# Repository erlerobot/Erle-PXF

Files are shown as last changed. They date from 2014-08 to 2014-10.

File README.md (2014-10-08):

Erle-PXF
===

Fork of the PXF board (http://github.com/diydrones/PXF) made by Erle Robotics.

This project is for developers, it will NOT be supported by the DIYDrones or Ardupilot suppoert forums for general users. This means we do not expect that this board will be plug and play, nor do we intend it to be.

Credit to Philip Rowse and Erle Robotics.

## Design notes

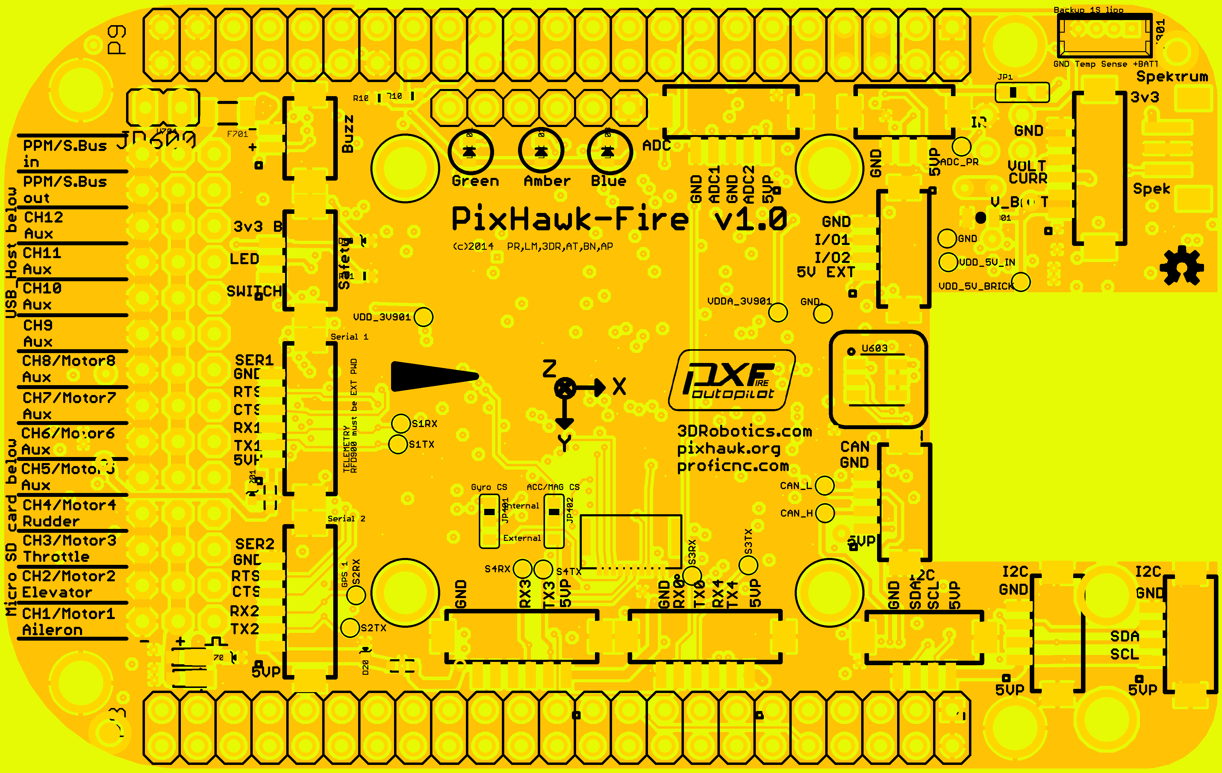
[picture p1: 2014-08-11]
3DModel/eagleUp/eagleUp_PixHawk_Fire_v1.1_board_top.png

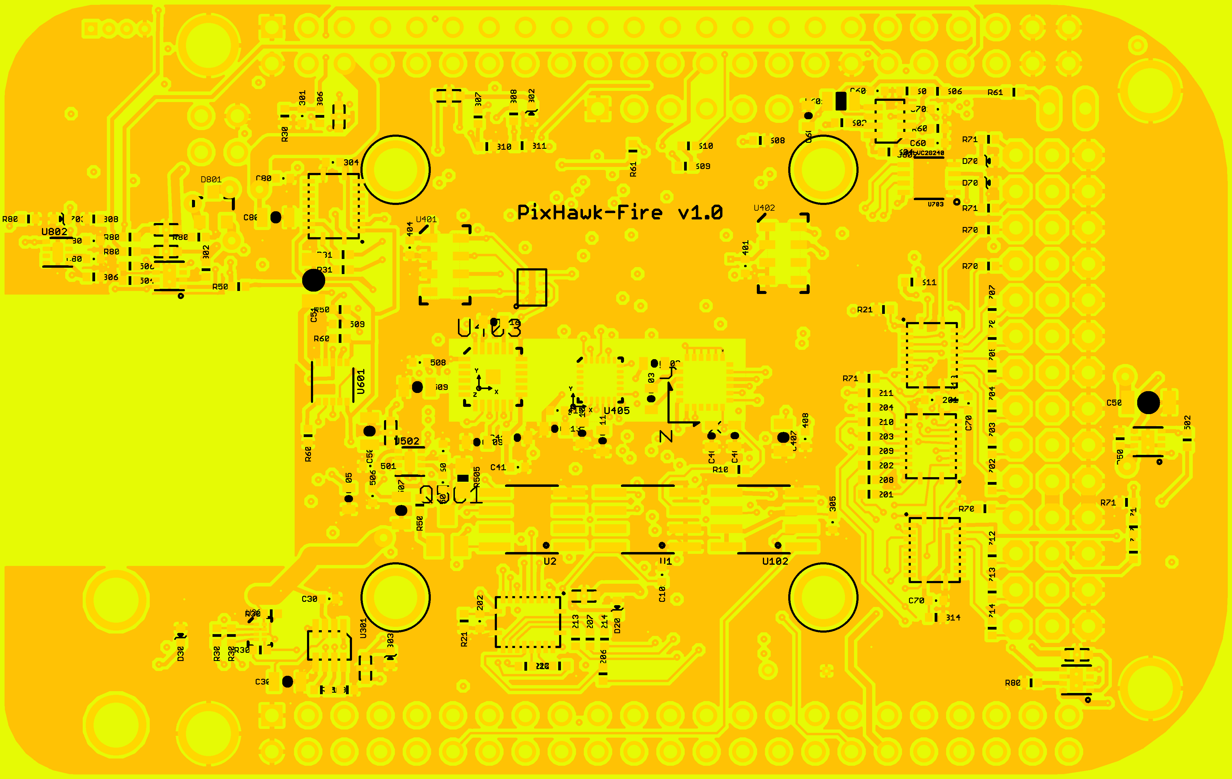
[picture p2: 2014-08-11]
3DModel/eagleUp/eagleUp_PixHawk_Fire_v1.1_board_bottom.png

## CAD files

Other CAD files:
3DModel/PXF-amarillo.skp

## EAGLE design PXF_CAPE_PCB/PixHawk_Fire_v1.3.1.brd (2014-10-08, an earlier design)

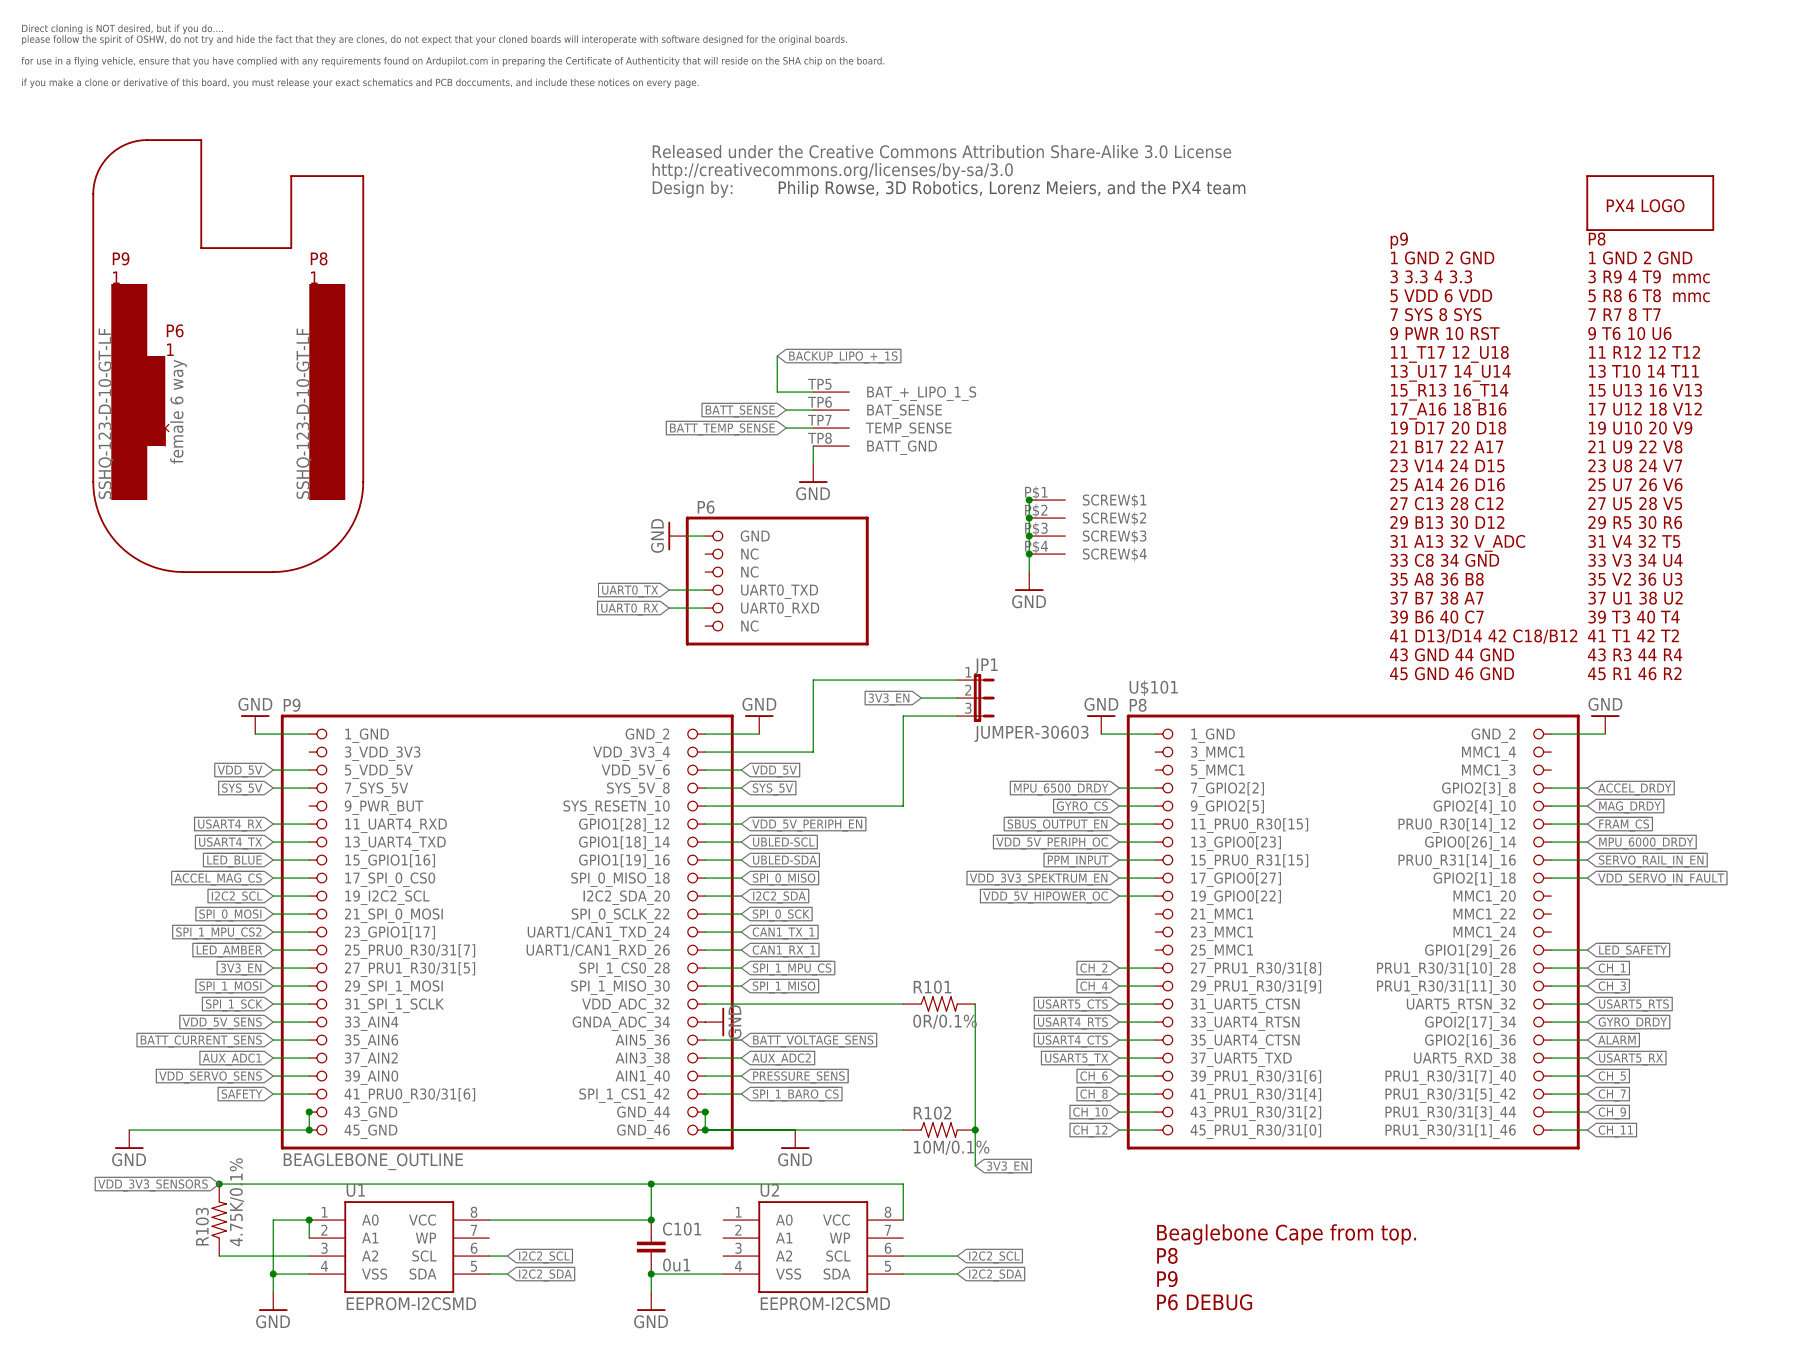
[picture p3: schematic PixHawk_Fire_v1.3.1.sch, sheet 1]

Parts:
C101: 0u1; 0402-CAP; PARTNO CC0402ZRY5V7BB104
JP1: JUMPER-30603; SJ_3_0603_PASTE1&2; PARTNO RC0603JR-070RL
R101: 0R/0.1%; 0402-RES; PARTNO RC0402FR-070RL
R102: 10M/0.1%; 0402-RES; PARTNO RC0402FR-0710ML
R103: 4.75K/0.1%; 0402-RES; PARTNO RC0402FR-074K75L
U1: EEPROM-I2CSMD; SO08; PARTNO AT24CS32-SSHM
U2: EEPROM-I2CSMD; SO08; PARTNO ATSHA204-SH-DA-TTR-ND
U$1: PX4-LOGO; PIXHAWK-FIRE-LOGO-30
U$6: CREATIVE_COMMONS
U$101: BEAGLEBONE_OUTLINE; BEAGLEBONE_SHIELD

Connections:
3V3_EN: JP1.2, R101.P$2 (2), R102.P$2 (2), U$101.73 (27_PRU1_R30/31[5]); also elsewhere on the board
3_VDD_3V3: U$101.49 (3_VDD_3V3)
!ACCEL_MAG_CS: U$101.63 (17_SPI_0_CS0); also elsewhere on the board
!FRAM_CS: U$101.12 (PRU0_R30[14]_12); also elsewhere on the board
!GYRO_CS: U$101.9 (9_GPIO2[5]); also elsewhere on the board
!LED_AMBER: U$101.71 (25_PRU0_R30/31[7]); also elsewhere on the board
!LED_BLUE: U$101.61 (15_GPIO1[16]); also elsewhere on the board
!LED_SAFETY: U$101.26 (GPIO1[29]_26); also elsewhere on the board
!SBUS_OUTPUT_EN: U$101.11 (11_PRU0_R30[15]); also elsewhere on the board
!VDD_5V_HIPOWER_OC: U$101.19 (19_GPIO0[22]); also elsewhere on the board
!VDD_5V_PERIPH_EN: U$101.58 (GPIO1[28]_12); also elsewhere on the board
!VDD_5V_PERIPH_OC: U$101.13 (13_GPIO0[23]); also elsewhere on the board
!VDD_SERVO_IN_FAULT: U$101.18 (GPIO2[1]_18); also elsewhere on the board
ACCEL_DRDY: U$101.8 (GPIO2[3]_8); also elsewhere on the board
ALARM: U$101.36 (GPIO2[16]_36); also elsewhere on the board
AUX_ADC1: U$101.83 (37_AIN2); also elsewhere on the board
AUX_ADC2: U$101.84 (AIN3_38); also elsewhere on the board
BACKUP_LIPO_+_1S: U$101.TP5 (BAT_+_LIPO_1_S); also elsewhere on the board
BATT_CURRENT_SENS: U$101.81 (35_AIN6); also elsewhere on the board
BATT_SENSE: U$101.TP6 (BAT_SENSE); also elsewhere on the board
BATT_TEMP_SENSE: U$101.TP7 (TEMP_SENSE); also elsewhere on the board
BATT_VOLTAGE_SENS: U$101.82 (AIN5_36); also elsewhere on the board
CH_1: U$101.28 (PRU1_R30/31[10]_28); also elsewhere on the board
CH_2: U$101.27 (27_PRU1_R30/31[8]); also elsewhere on the board
CH_3: U$101.30 (PRU1_R30/31[11]_30); also elsewhere on the board
CH_4: U$101.29 (29_PRU1_R30/31[9]); also elsewhere on the board
CH_5: U$101.40 (PRU1_R30/31[7]_40); also elsewhere on the board
CH_6: U$101.39 (39_PRU1_R30/31[6]); also elsewhere on the board
CH_7: U$101.42 (PRU1_R30/31[5]_42); also elsewhere on the board
CH_8: U$101.41 (41_PRU1_R30/31[4]); also elsewhere on the board
CH_9: U$101.44 (PRU1_R30/31[3]_44); also elsewhere on the board
CH_10: U$101.43 (43_PRU1_R30/31[2]); also elsewhere on the board
CH_11: U$101.46 (PRU1_R30/31[1]_46); also elsewhere on the board
CH_12: U$101.45 (45_PRU1_R30/31[0]); also elsewhere on the board
GND: C101.P$2 (2), R102.P$1 (1), U1.1 (A0), U1.2 (A1), U1.4 (VSS), U2.4 (VSS), U$101.1 (1_GND), U$101.2 (GND_2), U$101.47 (1_GND), U$101.48 (GND_2), U$101.80 (GNDA_ADC_34), U$101.89 (43_GND), U$101.90 (GND_44), U$101.91 (45_GND), U$101.92 (GND_46), U$101.93 (GND), U$101.P$1 (SCREW$1), U$101.P$2 (SCREW$2), U$101.P$3 (SCREW$3), U$101.P$4 (SCREW$4), U$101.TP8 (BATT_GND); also elsewhere on the board
GYRO_DRDY: U$101.34 (GPOI2[17]_34); also elsewhere on the board
I2C2_SCL: U1.6 (SCL), U2.6 (SCL), U$101.65 (19_I2C2_SCL); also elsewhere on the board
I2C2_SDA: U1.5 (SDA), U2.5 (SDA), U$101.66 (I2C2_SDA_20); also elsewhere on the board
MAG_DRDY: U$101.10 (GPIO2[4]_10); also elsewhere on the board
MPU_6000_DRDY: U$101.14 (GPIO0[26]_14); also elsewhere on the board
MPU_6500_DRDY: U$101.7 (7_GPIO2[2]); also elsewhere on the board
unnamed: R103.P$1 (1), U1.3 (A2)
unnamed: JP1.1, U$101.50 (VDD_3V3_4)
unnamed: JP1.3, U$101.56 (SYS_RESETN_10)
PPM_INPUT: U$101.15 (15_PRU0_R31[15]); also elsewhere on the board
PRESSURE_SENS: U$101.86 (AIN1_40); also elsewhere on the board
SAFETY: U$101.87 (41_PRU0_R30/31[6]); also elsewhere on the board
SERVO_RAIL_IN_!EN: U$101.16 (PRU0_R31[14]_16); also elsewhere on the board
SPI_0_MISO: U$101.64 (SPI_0_MISO_18); also elsewhere on the board
SPI_0_MOSI: U$101.67 (21_SPI_0_MOSI); also elsewhere on the board
SPI_0_SCK: U$101.68 (SPI_0_SCLK_22); also elsewhere on the board
SPI_1_!BARO_CS: U$101.88 (SPI_1_CS1_42); also elsewhere on the board
SPI_1_!MPU_CS: U$101.74 (SPI_1_CS0_28); also elsewhere on the board
SPI_1_!MPU_CS2: U$101.69 (23_GPIO1[17]); also elsewhere on the board
SPI_1_MISO: U$101.76 (SPI_1_MISO_30); also elsewhere on the board
SPI_1_MOSI: U$101.75 (29_SPI_1_MOSI); also elsewhere on the board
SPI_1_SCK: U$101.77 (31_SPI_1_SCLK); also elsewhere on the board
SYS_5V: U$101.53 (7_SYS_5V), U$101.54 (SYS_5V_8); also elsewhere on the board
UART0_RX: U$101.97 (UART0_RXD); also elsewhere on the board
UART0_TX: U$101.96 (UART0_TXD); also elsewhere on the board
UBLED-SCL: U$101.60 (GPIO1[18]_14); also elsewhere on the board
UBLED-SDA: U$101.62 (GPIO1[19]_16); also elsewhere on the board
USART4_CTS: U$101.35 (35_UART4_CTSN); also elsewhere on the board
USART4_RTS: U$101.33 (33_UART4_RTSN); also elsewhere on the board
USART4_RX: U$101.57 (11_UART4_RXD); also elsewhere on the board
USART4_TX: U$101.59 (13_UART4_TXD); also elsewhere on the board
USART5_CTS: U$101.31 (31_UART5_CTSN); also elsewhere on the board
USART5_RTS: U$101.32 (UART5_RTSN_32); also elsewhere on the board
USART5_RX: U$101.38 (UART5_RXD_38); also elsewhere on the board
USART5_TX: U$101.37 (37_UART5_TXD); also elsewhere on the board
VDD_3V3_SENSORS: C101.P$1 (1), R103.P$2 (2), U1.8 (VCC), U2.8 (VCC); also elsewhere on the board
VDD_3V3_SPEKTRUM_EN: U$101.17 (17_GPIO0[27]); also elsewhere on the board
VDD_5V: U$101.51 (5_VDD_5V), U$101.52 (VDD_5V_6); also elsewhere on the board
VDD_5V_SENS: U$101.79 (33_AIN4); also elsewhere on the board
VDD_ADC: R101.P$1 (1), U$101.78 (VDD_ADC_32)
VDD_SERVO_SENS: U$101.85 (39_AIN0); also elsewhere on the board

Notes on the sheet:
Beaglebone Cape from top. P8 P9 P6 DEBUG
Philip Rowse, 3D Robotics, Lorenz Meiers, and the PX4 team
Direct cloning is NOT desired, but if you do.... please follow the spirit of OSHW, do not try and hide the fact that they are clones, do not expect that your cloned boards will interoperate with software designed for the original boards. for use in a flying vehicle, ensure that you have complied wi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

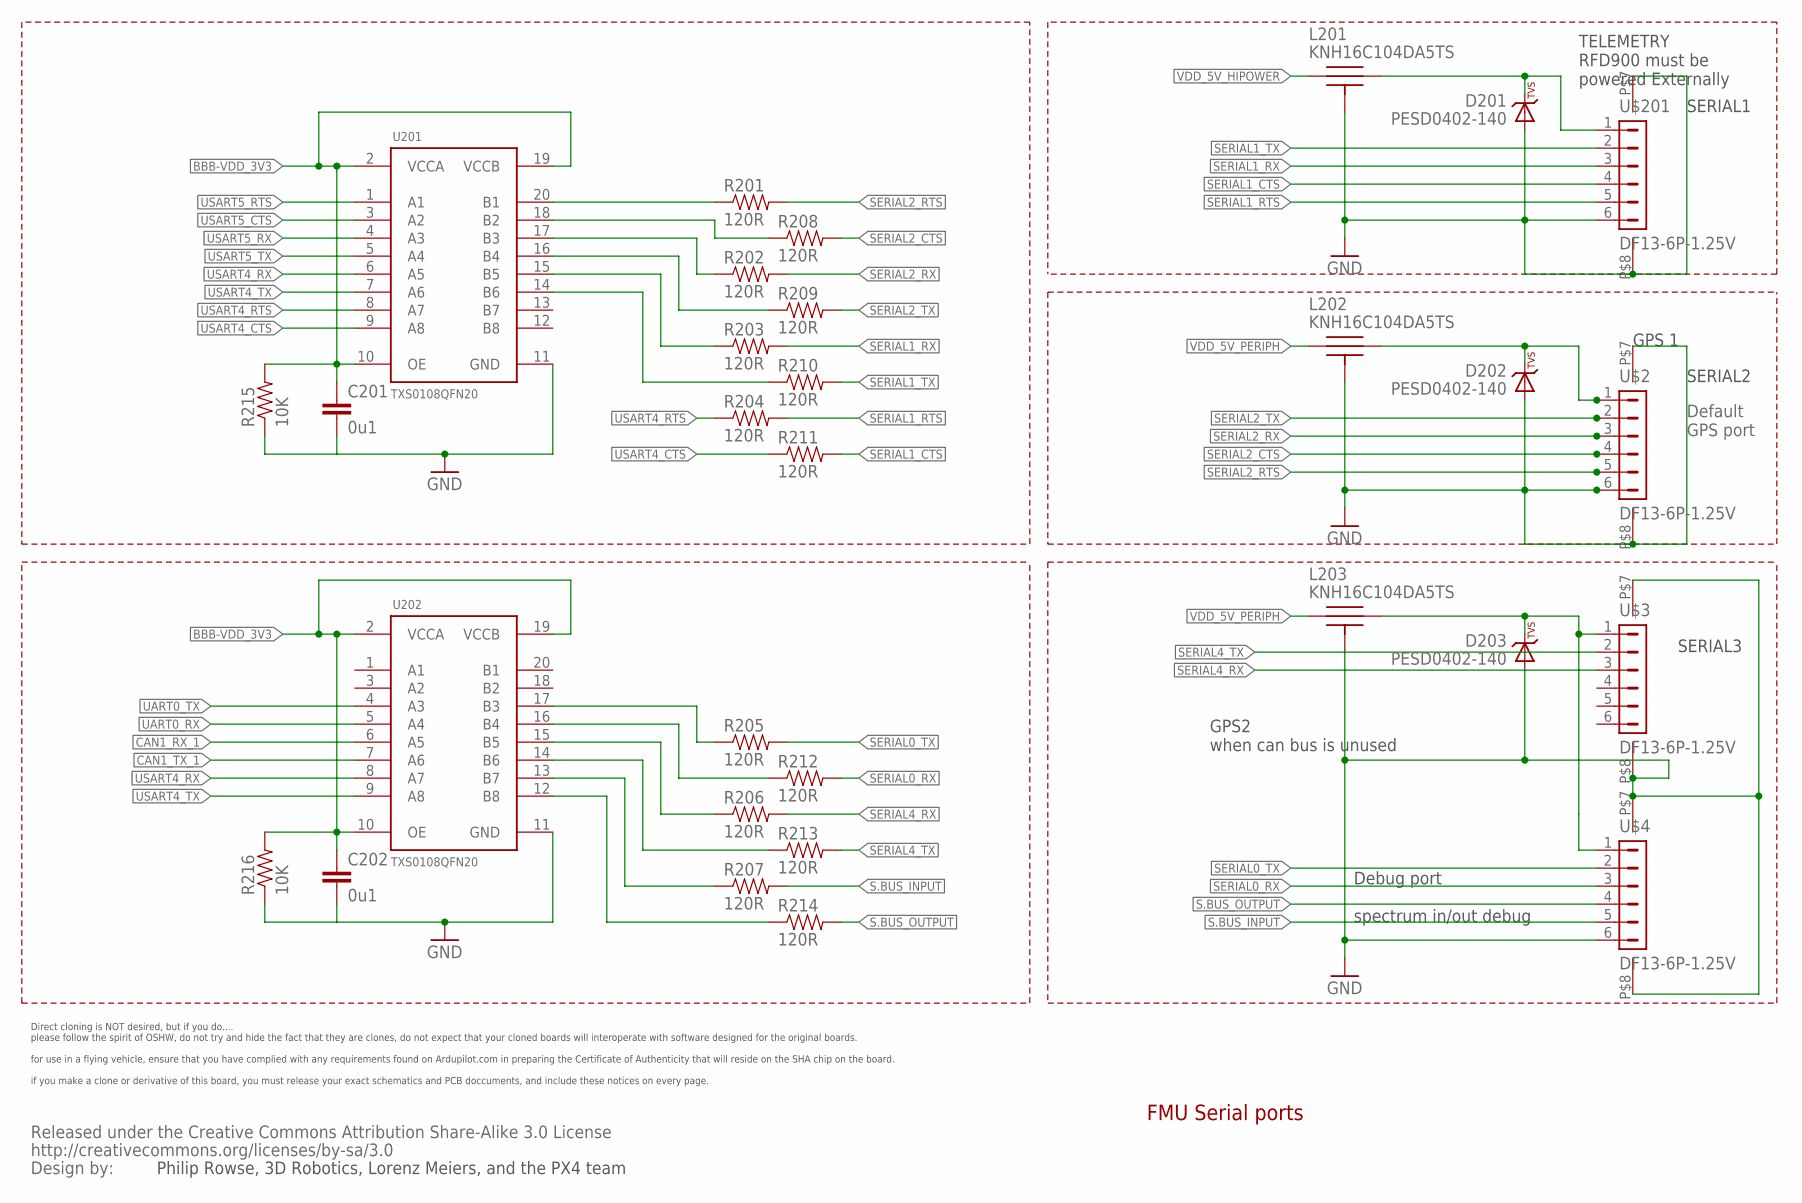
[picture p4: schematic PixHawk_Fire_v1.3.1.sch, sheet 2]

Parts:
C201, C202: 0u1; 0402-CAP; PARTNO CC0402ZRY5V7BB104
D201, D202, D203: PESD0402-140; 0402-TVS; PARTNO PESD0402-140
L201, L202, L203: KNH16C104DA5TS; KYOCERA-KNH16-DA; PARTNO KNH16C104DA5TS
R201, R202, R203, R204, R205, R206, R207, R208, R209, R210, R211, R212, R213, R214: 120R; 0402-RES; PARTNO RC0402FR-07120RL
R215, R216: 10K; 0402-RES; PARTNO ERA-2AEB103X
U201, U202: TXS0108QFN20; QFN20-RGY; PARTNO TXS0108ERGYR
U$2, U$3, U$4, U$201: DF13-6P-1.25V; DF13C-6P-1.25V; PARTNO DF13C-6P-1.25V(20)
U$5: CREATIVE_COMMONS

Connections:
BBB-VDD_3V3: C201.P$1 (1), C202.P$1 (1), R215.P$2 (2), R216.P$2 (2), U201.2 (VCCA), U201.10 (OE), U201.19 (VCCB), U202.2 (VCCA), U202.10 (OE), U202.19 (VCCB); also elsewhere on the board
CAN1_RX_1: U202.6 (A5); also elsewhere on the board
CAN1_TX_1: U202.7 (A6); also elsewhere on the board
GND: C201.P$2 (2), C202.P$2 (2), D201.A, D202.A, D203.A, L201.P$3, L201.P$4, L201.P$5, L202.P$3, L202.P$4, L202.P$5, L203.P$3, L203.P$4, L203.P$5, R215.P$1 (1), R216.P$1 (1), U201.11 (GND), U202.11 (GND), U$2.6, U$2.P$7, U$2.P$8, U$3.P$7, U$3.P$8, U$4.6, U$4.P$7, U$4.P$8, U$201.6, U$201.P$7, U$201.P$8; also elsewhere on the board
unnamed: D201.C, L201.P$2, U$201.1
unnamed: R205.P$1 (1), U202.17 (B3)
unnamed: R212.P$1 (1), U202.16 (B4)
unnamed: R208.P$1 (1), U201.18 (B2)
unnamed: R201.P$1 (1), U201.20 (B1)
unnamed: R202.P$1 (1), U201.17 (B3)
unnamed: R209.P$1 (1), U201.16 (B4)
unnamed: R203.P$1 (1), U201.15 (B5)
unnamed: R210.P$1 (1), U201.14 (B6)
unnamed: R207.P$1 (1), U202.13 (B7)
unnamed: R214.P$1 (1), U202.12 (B8)
unnamed: R206.P$1 (1), U202.15 (B5)
unnamed: R213.P$1 (1), U202.14 (B6)
unnamed: D203.C, L203.P$2, U$3.1, U$4.1
unnamed: D202.C, L202.P$2, U$2.1
S.BUS_INPUT: R207.P$2 (2), U$4.5; also elsewhere on the board
S.BUS_OUTPUT: R214.P$2 (2), U$4.4; also elsewhere on the board
SERIAL0_RX: R212.P$2 (2), U$4.3
SERIAL0_TX: R205.P$2 (2), U$4.2
SERIAL1_CTS: R211.P$2 (2), U$201.4
SERIAL1_RTS: R204.P$2 (2), U$201.5
SERIAL1_RX: R203.P$2 (2), U$201.3; also elsewhere on the board
SERIAL1_TX: R210.P$2 (2), U$201.2; also elsewhere on the board
SERIAL2_CTS: R208.P$2 (2), U$2.4
SERIAL2_RTS: R201.P$2 (2), U$2.5
SERIAL2_RX: R202.P$2 (2), U$2.3; also elsewhere on the board
SERIAL2_TX: R209.P$2 (2), U$2.2; also elsewhere on the board
SERIAL4_RX: R206.P$2 (2), U$3.3; also elsewhere on the board
SERIAL4_TX: R213.P$2 (2), U$3.2; also elsewhere on the board
UART0_RX: U202.5 (A4); also elsewhere on the board
UART0_TX: U202.4 (A3); also elsewhere on the board
USART4_CTS: R211.P$1 (1), U201.9 (A8); also elsewhere on the board
USART4_RTS: R204.P$1 (1), U201.8 (A7); also elsewhere on the board
USART4_RX: U201.6 (A5), U202.8 (A7); also elsewhere on the board
USART4_TX: U201.7 (A6), U202.9 (A8); also elsewhere on the board
USART5_CTS: U201.3 (A2); also elsewhere on the board
USART5_RTS: U201.1 (A1); also elsewhere on the board
USART5_RX: U201.4 (A3); also elsewhere on the board
USART5_TX: U201.5 (A4); also elsewhere on the board
VDD_5V_HIPOWER: L201.P$1; also elsewhere on the board
VDD_5V_PERIPH: L202.P$1, L203.P$1; also elsewhere on the board

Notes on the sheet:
FMU Serial ports
SERIAL2
SERIAL1
SERIAL3
Default GPS port
TELEMETRY RFD900 must be powered Externally
GPS 1
Debug port spectrum in/out debug
GPS2 when can bus is unused
Philip Rowse, 3D Robotics, Lorenz Meiers, and the PX4 team
Direct cloning is NOT desired, but if you do.... please follow the spirit of OSHW, do not try and hide the fact that they are clones, do not expect that your cloned boards will interoperate with software designed for the original boards. for use in a flying vehicle, ensure that you have complied wi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

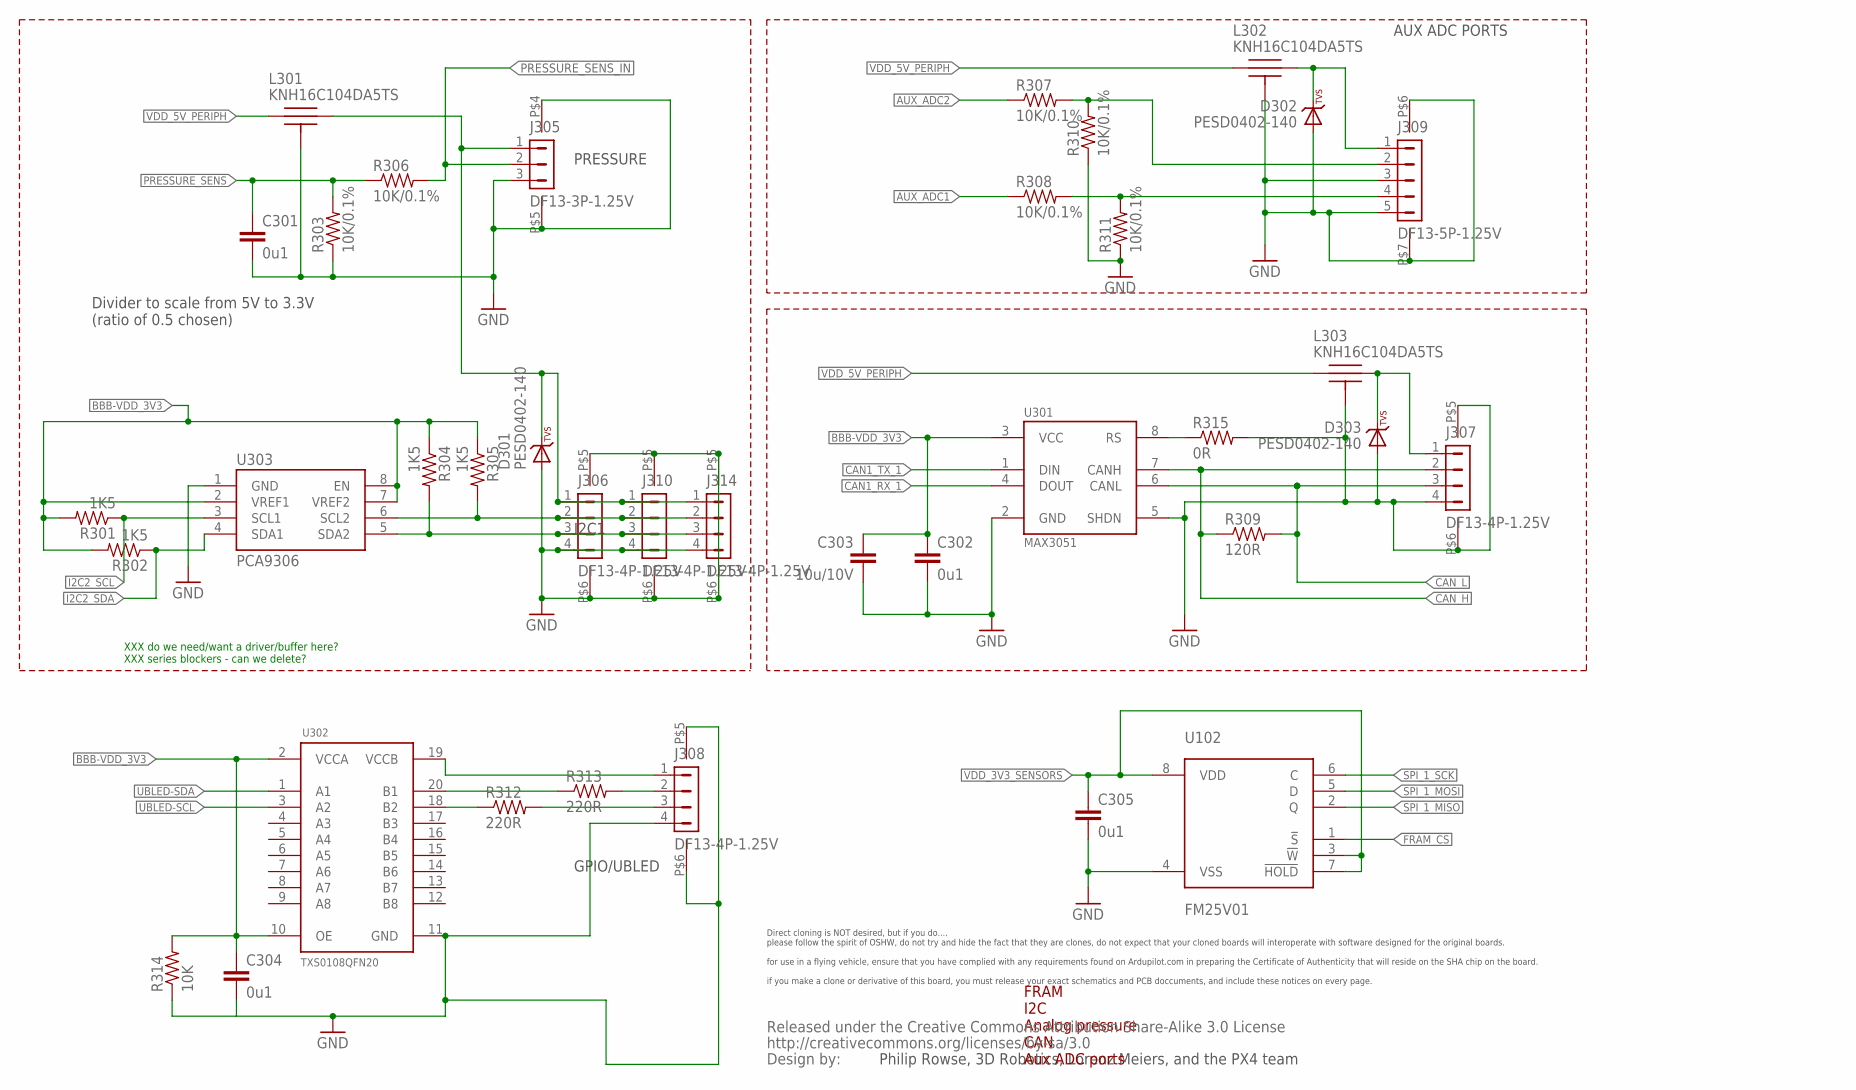
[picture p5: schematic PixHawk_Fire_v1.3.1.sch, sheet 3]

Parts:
C301, C302, C304, C305: 0u1; 0402-CAP; PARTNO CC0402ZRY5V7BB104
C303: 10u/10V; 0805-CAP; PARTNO CC0805ZKY5V6BB106
D301, D302, D303: PESD0402-140; 0402-TVS; PARTNO PESD0402-140
J305: DF13-3P-1.25V; DF13C-3P-1.25V; PARTNO DF13C-3P-1.25V(20)
J306, J307, J308, J310, J314: DF13-4P-1.25V; DF13C-4P-1.25V; PARTNO DF13C-4P-1.25V(20)
J309: DF13-5P-1.25V; DF13C-5P-1.25V; PARTNO DF13C-5P-1.25V(20)
L301, L302, L303: KNH16C104DA5TS; KYOCERA-KNH16-DA; PARTNO KNH16C104DA5TS
R301, R302, R304, R305: 1K5; 0402-RES; PARTNO RC0402FR-071K5L
R303, R306, R307, R308, R310, R311: 10K/0.1%; 0402-RES; PARTNO ERA-2AEB103X
R309: 120R; 0402-RES; PARTNO RC0402FR-07120RL
R312, R313: 220R; 0402-RES; PARTNO RC0402FR-07220RL
R314: 10K; 0402-RES; PARTNO ERA-2AEB103X
R315: 0R; 0402-RES; PARTNO RC0402FR-070RL
U102: FM25V01; SO08; PARTNO FM25V01-G
U301: MAX3051; SOT23-8; PARTNO MAX3051EKA
U302: TXS0108QFN20; QFN20-RGY; PARTNO TXS0108ERGYR
U303: PCA9306; PARTNO PCA9306DQER
U$7: CREATIVE_COMMONS

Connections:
!FRAM_CS: U102.1 (!S); also elsewhere on the board
AUX_ADC1: R308.P$1 (1); also elsewhere on the board
AUX_ADC2: R307.P$1 (1); also elsewhere on the board
BBB-VDD_3V3: C302.P$1 (1), C303.P$1 (1), C304.P$1 (1), R301.P$2 (2), R302.P$2 (2), R304.P$1 (1), R305.P$1 (1), R314.P$2 (2), U301.3 (VCC), U302.2 (VCCA), U302.10 (OE), U303.2 (VREF1), U303.7 (VREF2), U303.8 (EN); also elsewhere on the board
CAN1_RX_1: U301.4 (DOUT); also elsewhere on the board
CAN1_TX_1: U301.1 (DIN); also elsewhere on the board
CAN_H: J307.2, R309.P$1 (1), U301.7 (CANH); also elsewhere on the board
CAN_L: J307.3, R309.P$2 (2), U301.6 (CANL); also elsewhere on the board
FMU_AUX_ADC1_PROT: J309.4, R308.P$2 (2), R311.P$2 (2)
FMU_AUX_ADC2_PROT: J309.2, R307.P$2 (2), R310.P$2 (2)
GND: C301.P$2 (2), C302.P$2 (2), C303.P$2 (2), C304.P$2 (2), C305.P$2 (2), D301.A, D302.A, D303.A, J305.3, J305.P$4, J305.P$5, J306.4, J306.P$5, J306.P$6, J307.4, J307.P$5, J307.P$6, J308.4, J308.P$5, J308.P$6, J309.3, J309.5, J309.P$6, J309.P$7, J310.4, J310.P$5, J310.P$6, J314.4, J314.P$5, J314.P$6, L301.P$3, L301.P$4, L301.P$5, L302.P$3, L302.P$4, L302.P$5, L303.P$3, L303.P$4, L303.P$5, R303.P$1 (1), R310.P$1 (1), R311.P$1 (1), R314.P$1 (1), R315.P$2 (2), U102.4 (VSS), U301.2 (GND), U301.5 (SHDN), U302.11 (GND), U303.1 (GND); also elsewhere on the board
I2C2_SCL: R301.P$1 (1), U303.3 (SCL1); also elsewhere on the board
I2C2_SDA: R302.P$1 (1), U303.4 (SDA1); also elsewhere on the board
unnamed: R313.P$1 (1), U302.20 (B1)
unnamed: J306.2, J310.2, J314.2, R305.P$2 (2), U303.6 (SCL2)
unnamed: J306.3, J310.3, J314.3, R304.P$2 (2), U303.5 (SDA2)
unnamed: R312.P$1 (1), U302.18 (B2)
unnamed: D301.C, J305.1, J306.1, J310.1, J314.1, L301.P$2
unnamed: J308.3, R312.P$2 (2)
unnamed: J308.2, R313.P$2 (2)
unnamed: J308.1, U302.19 (VCCB)
unnamed: D303.C, J307.1, L303.P$2
unnamed: R315.P$1 (1), U301.8 (RS)
unnamed: D302.C, J309.1, L302.P$2
PRESSURE_SENS: C301.P$1 (1), R303.P$2 (2), R306.P$1 (1); also elsewhere on the board
PRESSURE_SENS_IN: J305.2, R306.P$2 (2); also elsewhere on the board
SPI_1_MISO: U102.2 (Q); also elsewhere on the board
SPI_1_MOSI: U102.5 (D); also elsewhere on the board
SPI_1_SCK: U102.6 (C); also elsewhere on the board
UBLED-SCL: U302.3 (A2); also elsewhere on the board
UBLED-SDA: U302.1 (A1); also elsewhere on the board
VDD_3V3_SENSORS: C305.P$1 (1), U102.3 (!W), U102.7 (!HOLD), U102.8 (VDD); also elsewhere on the board
VDD_5V_PERIPH: L301.P$1, L302.P$1, L303.P$1; also elsewhere on the board

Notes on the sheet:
PRESSURE
XXX do we need/want a driver/buffer here? XXX series blockers - can we delete?
I2C1
AUX ADC PORTS
FRAM I2C Analog pressure CAN Aux ADC ports
Divider to scale from 5V to 3.3V (ratio of 0.5 chosen)
GPIO/UBLED
Philip Rowse, 3D Robotics, Lorenz Meiers, and the PX4 team
Direct cloning is NOT desired, but if you do.... please follow the spirit of OSHW, do not try and hide the fact that they are clones, do not expect that your cloned boards will interoperate with software designed for the original boards. for use in a flying vehicle, ensure that you have complied wi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

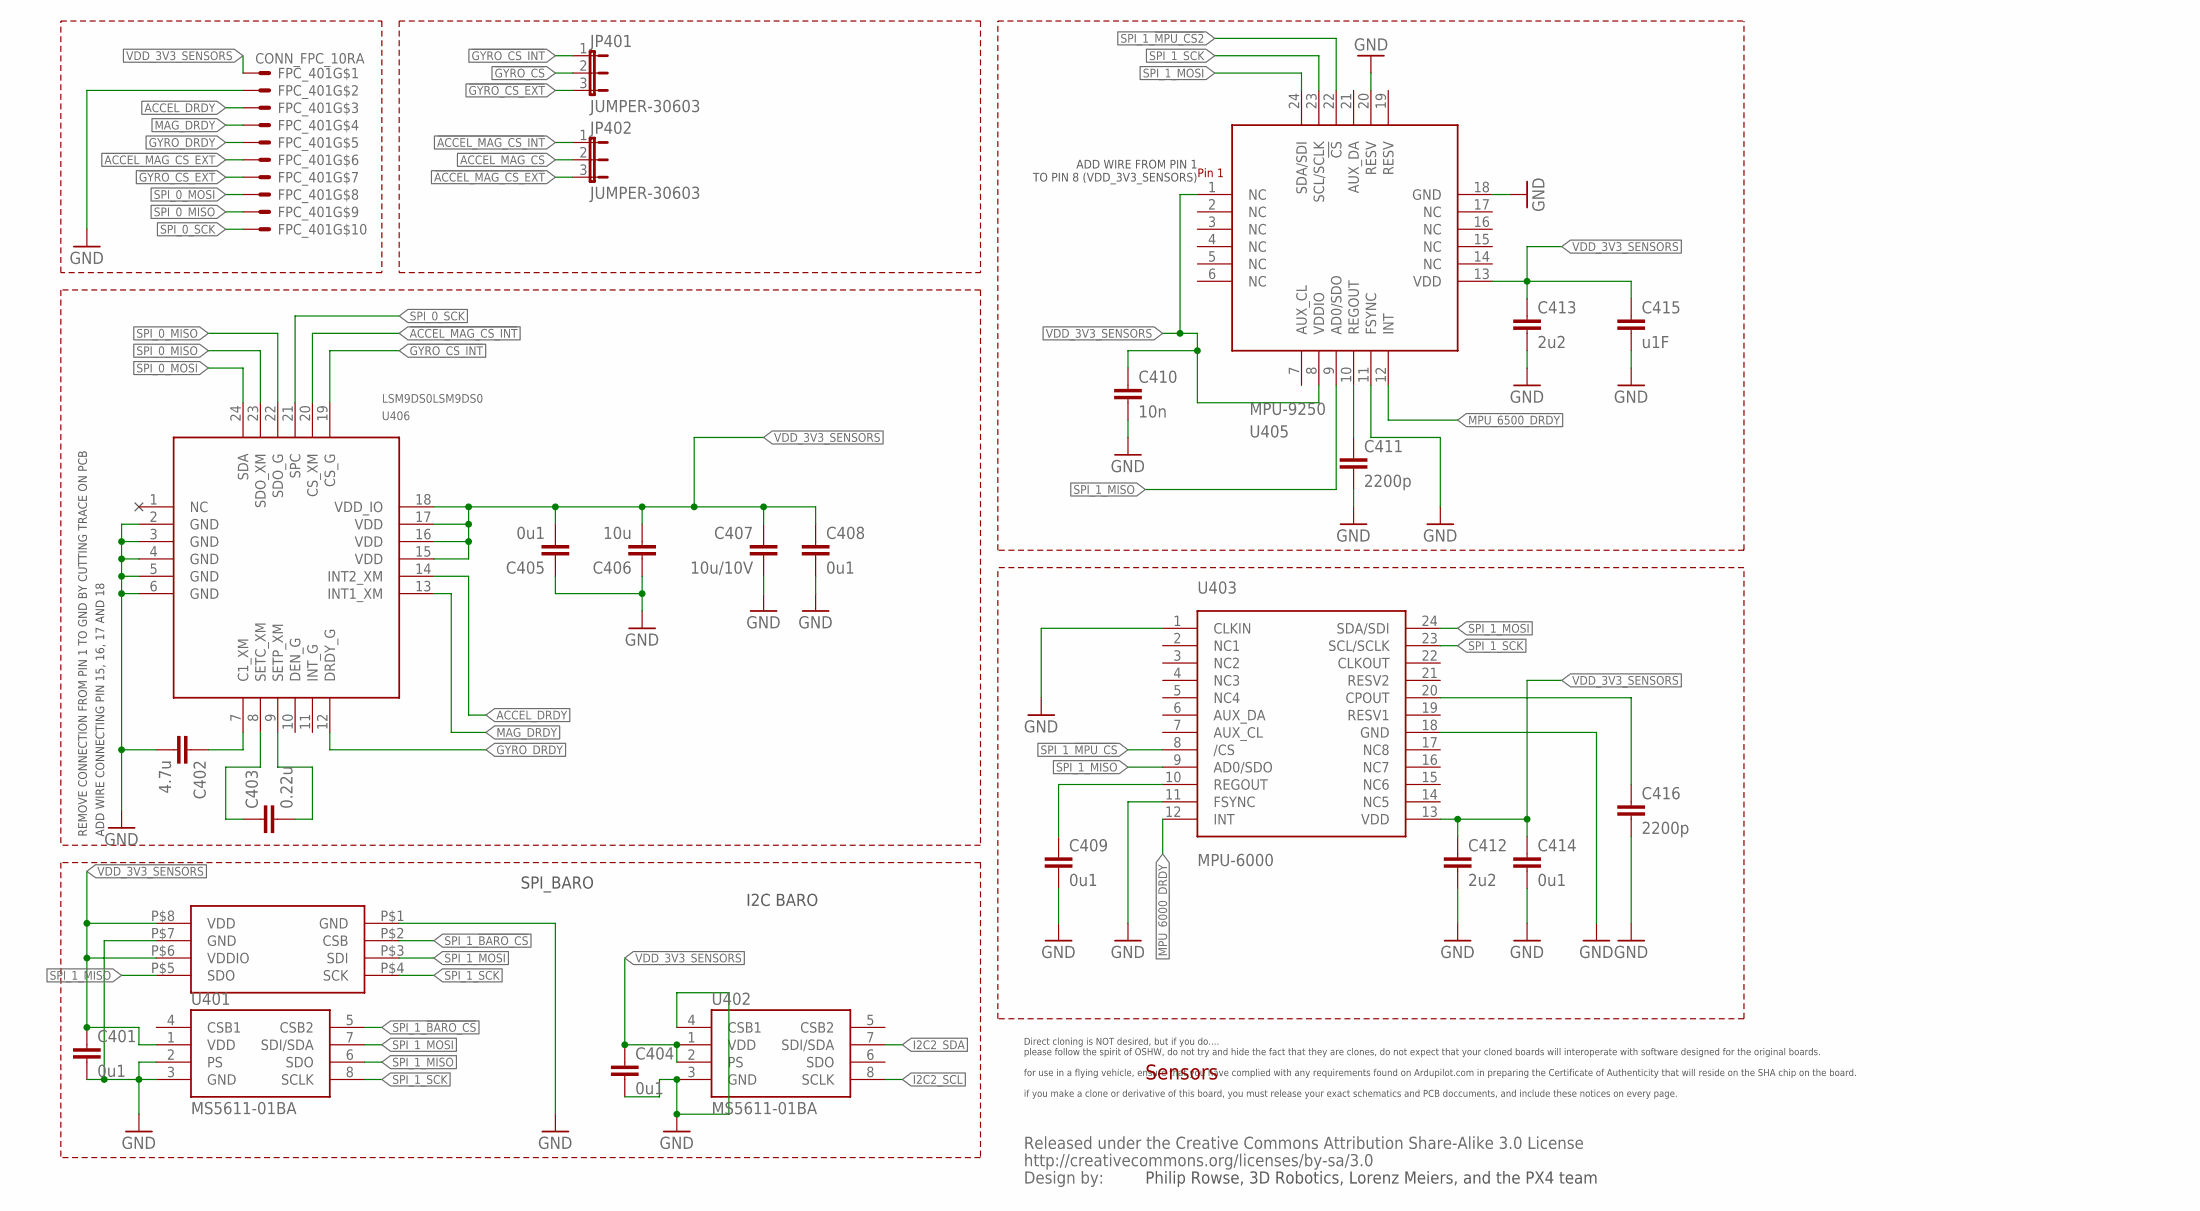
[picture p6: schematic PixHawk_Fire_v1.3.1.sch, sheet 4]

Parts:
C401, C404, C408: 0u1; 0402-CAP; PARTNO CC0402ZRY5V7BB104
C402: 4.7u; 0603-CAP; PARTNO C1608X7S1A475K080AC
C403: 0.22u; 0603-CAP; PARTNO CL10B224JP8NNNC
C405: 0u1; 0603-CAP; PARTNO CL10B104JO8NNNC
C406: 10u; 0603-CAP; PARTNO C1608X7S0J106M080AC
C407: 10u/10V; 0805-CAP; PARTNO CC0805ZKY5V6BB106
C409: 0u1; 0603-CAP; PARTNO C0603C104K4RACTU
C410: 10n; 0603-CAP; PARTNO C0603C103J5RAC7411
C411, C416: 2200p; 0603-CAP; PARTNO C0603C222J5RACTU
C412: 2u2; 0603-CAP; PARTNO CGA3E1X7R0J225K080AC
C413: 2u2; 0603-CAP
C414: 0u1; 0402-CAP; PARTNO C0603C104K4RACTU
C415: u1F; 0402-CAP; PARTNO CC0402ZRY5V7BB104
FPC_401: CONN_FPC_10RA; 51281-1094; PARTNO 0512811094
JP401, JP402: JUMPER-30603; SJ_3_0603_PASTE1&2; PARTNO RC0603JR-070RL
U401, U402: MS5611-01BA; PARTNO MS5611-01BA
U403: MPU-6000; QFN-24; PARTNO MPU-6000
U405: MPU-9250; MPU-6500; PARTNO MPU-9250
U406: LSM9DS0LSM9DS0; LSM9DS0; PARTNO LSM9DS0TR
U407: BMP280_PRELIM; PARTNO *
U$8: CREATIVE_COMMONS

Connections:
!ACCEL_MAG_CS: JP402.2; also elsewhere on the board
!ACCEL_MAG_CS_EXT: FPC_401.6, JP402.3
!ACCEL_MAG_CS_INT: JP402.1, U406.20 (CS_XM)
!GYRO_CS: JP401.2; also elsewhere on the board
!GYRO_CS_EXT: FPC_401.7, JP401.3
!GYRO_CS_INT: JP401.1, U406.19 (CS_G)
ACCEL_DRDY: FPC_401.3, U406.14 (INT2_XM); also elsewhere on the board
GND: C401.P$2 (2), C402.P$2 (2), C404.P$2 (2), C405.P$1 (1), C406.P$1 (1), C407.P$2 (2), C408.P$2 (2), C409.P$2 (2), C410.P$2 (2), C411.P$2 (2), C412.P$2 (2), C413.P$2 (2), C414.P$2 (2), C415.P$2 (2), C416.P$2 (2), FPC_401.2, U401.2 (PS), U401.3 (GND), U402.3 (GND), U402.4 (CSB1), U403.1 (CLKIN), U403.11 (FSYNC), U403.18 (GND), U405.11 (FSYNC), U405.18 (GND), U405.20 (RESV), U406.2 (GND), U406.3 (GND), U406.4 (GND), U406.5 (GND), U406.6 (GND), U407.P$1 (GND), U407.P$7 (GND); also elsewhere on the board
GYRO_DRDY: FPC_401.5, U406.12 (DRDY_G); also elsewhere on the board
I2C2_SCL: U402.8 (SCLK); also elsewhere on the board
I2C2_SDA: U402.7 (SDI/SDA); also elsewhere on the board
MAG_DRDY: FPC_401.4, U406.13 (INT1_XM); also elsewhere on the board
MPU_6000_DRDY: U403.12 (INT); also elsewhere on the board
MPU_6500_DRDY: U405.12 (INT); also elsewhere on the board
unnamed: C402.P$1 (1), U406.7 (C1_XM)
unnamed: C403.P$2 (2), U406.9 (SETP_XM)
unnamed: C411.P$1 (1), U405.10 (REGOUT)
unnamed: C403.P$1 (1), U406.8 (SETC_XM)
unnamed: C409.P$1 (1), U403.10 (REGOUT)
unnamed: C416.P$1 (1), U403.20 (CPOUT)
SPI_0_MISO: FPC_401.9, U406.22 (SDO_G), U406.23 (SDO_XM); also elsewhere on the board
SPI_0_MOSI: FPC_401.8, U406.24 (SDA); also elsewhere on the board
SPI_0_SCK: FPC_401.10, U406.21 (SPC); also elsewhere on the board
SPI_1_!BARO_CS: U401.5 (CSB2), U407.P$2 (CSB); also elsewhere on the board
SPI_1_!MPU_CS: U403.8 (/CS); also elsewhere on the board
SPI_1_!MPU_CS2: U405.22 (!CS); also elsewhere on the board
SPI_1_MISO: U401.6 (SDO), U403.9 (AD0/SDO), U405.9 (AD0/SDO), U407.P$5 (SDO); also elsewhere on the board
SPI_1_MOSI: U401.7 (SDI/SDA), U403.24 (SDA/SDI), U405.24 (SDA/SDI), U407.P$3 (SDI); also elsewhere on the board
SPI_1_SCK: U401.8 (SCLK), U403.23 (SCL/SCLK), U405.23 (SCL/SCLK), U407.P$4 (SCK); also elsewhere on the board
VDD_3V3_SENSORS: C401.P$1 (1), C404.P$1 (1), C405.P$2 (2), C406.P$2 (2), C407.P$1 (1), C408.P$1 (1), C410.P$1 (1), C412.P$1 (1), C413.P$1 (1), C414.P$1 (1), C415.P$1 (1), FPC_401.1, U401.1 (VDD), U402.1 (VDD), U402.2 (PS), U403.13 (VDD), U405.1 (NC), U405.8 (VDDIO), U405.13 (VDD), U406.15 (VDD), U406.16 (VDD), U406.17 (VDD), U406.18 (VDD_IO), U407.P$6 (VDDIO), U407.P$8 (VDD); also elsewhere on the board

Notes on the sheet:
Sensors
I2C BARO
SPI_BARO
REMOVE CONNECTION FROM PIN 1 TO GND BY CUTTING TRACE ON PCB
ADD WIRE FROM PIN 1 TO PIN 8 (VDD_3V3_SENSORS)
ADD WIRE CONNECTING PIN 15, 16, 17 AND 18
Philip Rowse, 3D Robotics, Lorenz Meiers, and the PX4 team
Direct cloning is NOT desired, but if you do.... please follow the spirit of OSHW, do not try and hide the fact that they are clones, do not expect that your cloned boards will interoperate with software designed for the original boards. for use in a flying vehicle, ensure that you have complied wi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

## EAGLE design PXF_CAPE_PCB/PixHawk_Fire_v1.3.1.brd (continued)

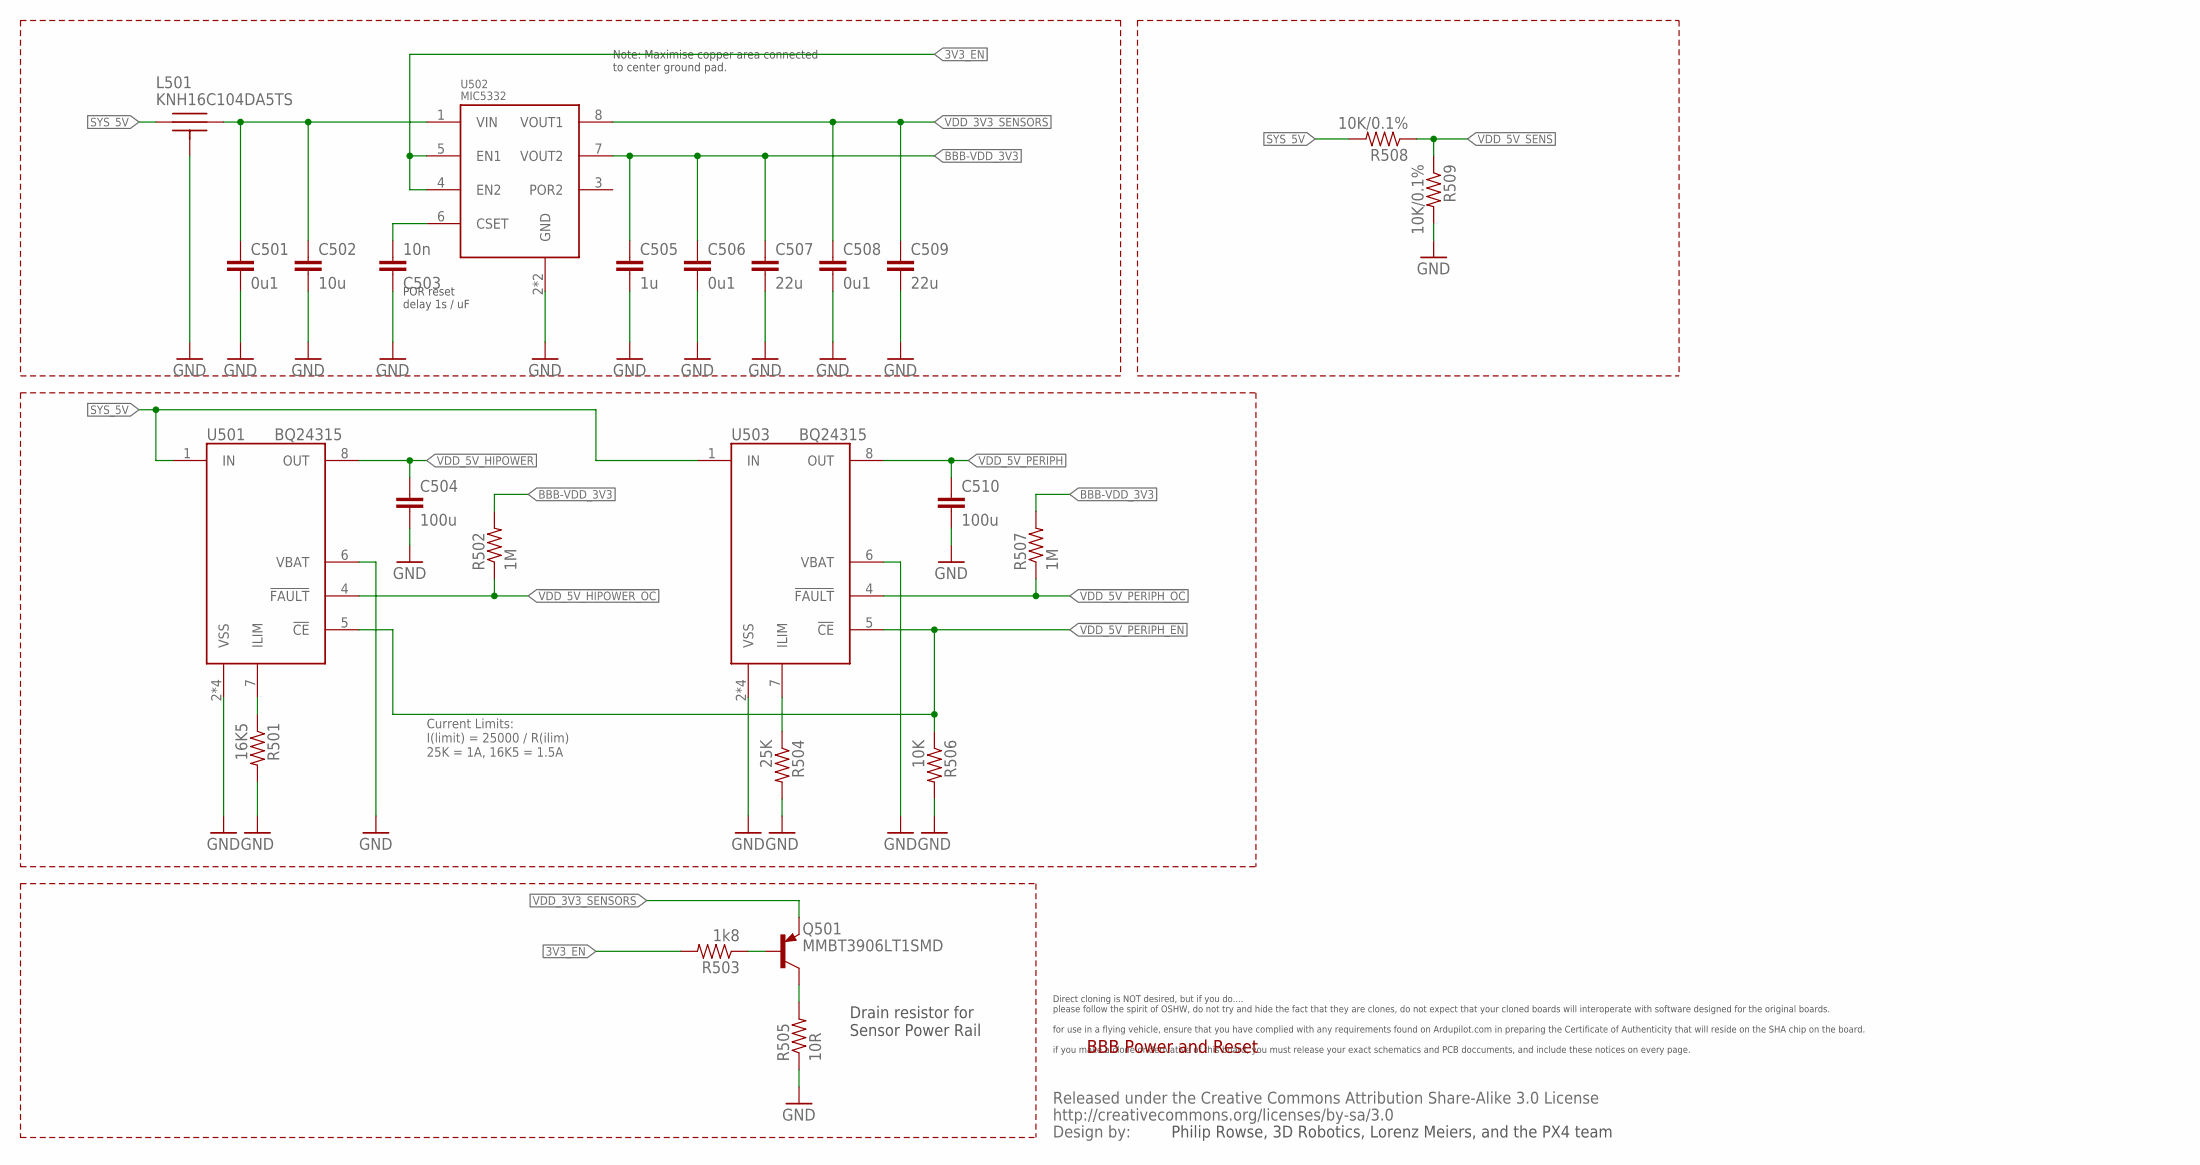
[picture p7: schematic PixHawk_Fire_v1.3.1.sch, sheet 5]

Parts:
C501, C506, C508: 0u1; 0402-CAP; PARTNO CC0402ZRY5V7BB104
C502: 10u; 0805-CAP; PARTNO C1608X7S0J106M080AC
C503: 10n; 0402-CAP; PARTNO CC0402KRX7R7BB103
C504, C510: 100u; 1206-CAP; PARTNO C3216X5R1A107M160AC
C505: 1u; 0603-CAP; PARTNO CC0603ZRY5V7BB105
C507, C509: 22u; 0805-CAP; PARTNO CC0805MKX5R5BB226
L501: KNH16C104DA5TS; KYOCERA-KNH16-DA; PARTNO KNH16C104DA5TS
Q501: MMBT3906LT1SMD; SOT23-BEC; PARTNO MMBT3906LT1G
R501: 16K5; 0402-RES; PARTNO RMCF0402FT16K5
R502, R507: 1M; 0402-RES; PARTNO MCR01MRTF1004
R503: 1k8; 0402-RES; PARTNO RC0402FR-071K8L
R504: 25K; 0402-RES; PARTNO RMCF0402FT25K5
R505: 10R; 0603-RES; PARTNO RC0402FR-0710RL
R506: 10K; 0402-RES; PARTNO ERA-2AEB103X
R508, R509: 10K/0.1%; 0402-RES; PARTNO ERA-2AEB103X
U501, U503: BQ24315; QFN8-DSG; PARTNO BQ24315DSGR
U502: MIC5332; MLF-8-EPAD; PARTNO MIC5332-SSYMT
U$9: CREATIVE_COMMONS

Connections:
3V3_EN: R503.P$2 (2), U502.4 (EN2), U502.5 (EN1); also elsewhere on the board
!VDD_5V_HIPOWER_OC: R502.P$1 (1), U501.4 (!FAULT); also elsewhere on the board
!VDD_5V_PERIPH_EN: R506.P$1 (1), U501.5 (!CE), U503.5 (!CE); also elsewhere on the board
!VDD_5V_PERIPH_OC: R507.P$1 (1), U503.4 (!FAULT); also elsewhere on the board
BBB-VDD_3V3: C505.P$1 (1), C506.P$1 (1), C507.P$1 (1), R502.P$2 (2), R507.P$2 (2), U502.7 (VOUT2); also elsewhere on the board
FMU-VDD_5V5: C501.P$1 (1), C502.P$1 (1), L501.P$2, U502.1 (VIN)
GND: C501.P$2 (2), C502.P$2 (2), C503.P$1 (1), C504.P$2 (2), C505.P$2 (2), C506.P$2 (2), C507.P$2 (2), C508.P$2 (2), C509.P$2 (2), C510.P$2 (2), L501.P$3, L501.P$4, L501.P$5, R501.P$2 (2), R504.P$2 (2), R505.1, R506.P$2 (2), R509.P$2 (2), U501.2 (VSS), U501.6 (VBAT), U501.GND (VSS), U501.P$2 (VSS), U501.P$3 (VSS), U502.2 (GND), U502.GND, U503.2 (VSS), U503.6 (VBAT), U503.GND (VSS), U503.P$2 (VSS), U503.P$3 (VSS); also elsewhere on the board
unnamed: C503.P$2 (2), U502.6 (CSET)
unnamed: R504.P$1 (1), U503.7 (ILIM)
unnamed: Q501.C, R505.2
unnamed: Q501.B, R503.P$1 (1)
unnamed: R501.P$1 (1), U501.7 (ILIM)
SYS_5V: L501.P$1, R508.P$2 (2), U501.1 (IN), U503.1 (IN); also elsewhere on the board
VDD_3V3_SENSORS: C508.P$1 (1), C509.P$1 (1), Q501.E, U502.8 (VOUT1); also elsewhere on the board
VDD_5V_HIPOWER: C504.P$1 (1), U501.8 (OUT); also elsewhere on the board
VDD_5V_PERIPH: C510.P$1 (1), U503.8 (OUT); also elsewhere on the board
VDD_5V_SENS: R508.P$1 (1), R509.P$1 (1); also elsewhere on the board

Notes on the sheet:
BBB Power and Reset
Note: Maximise copper area connected to center ground pad.
POR reset delay 1s / uF
Current Limits: I(limit) = 25000 / R(ilim) 25K = 1A, 16K5 = 1.5A
Drain resistor for Sensor Power Rail
Philip Rowse, 3D Robotics, Lorenz Meiers, and the PX4 team
Direct cloning is NOT desired, but if you do.... please follow the spirit of OSHW, do not try and hide the fact that they are clones, do not expect that your cloned boards will interoperate with software designed for the original boards. for use in a flying vehicle, ensure that you have complied wi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

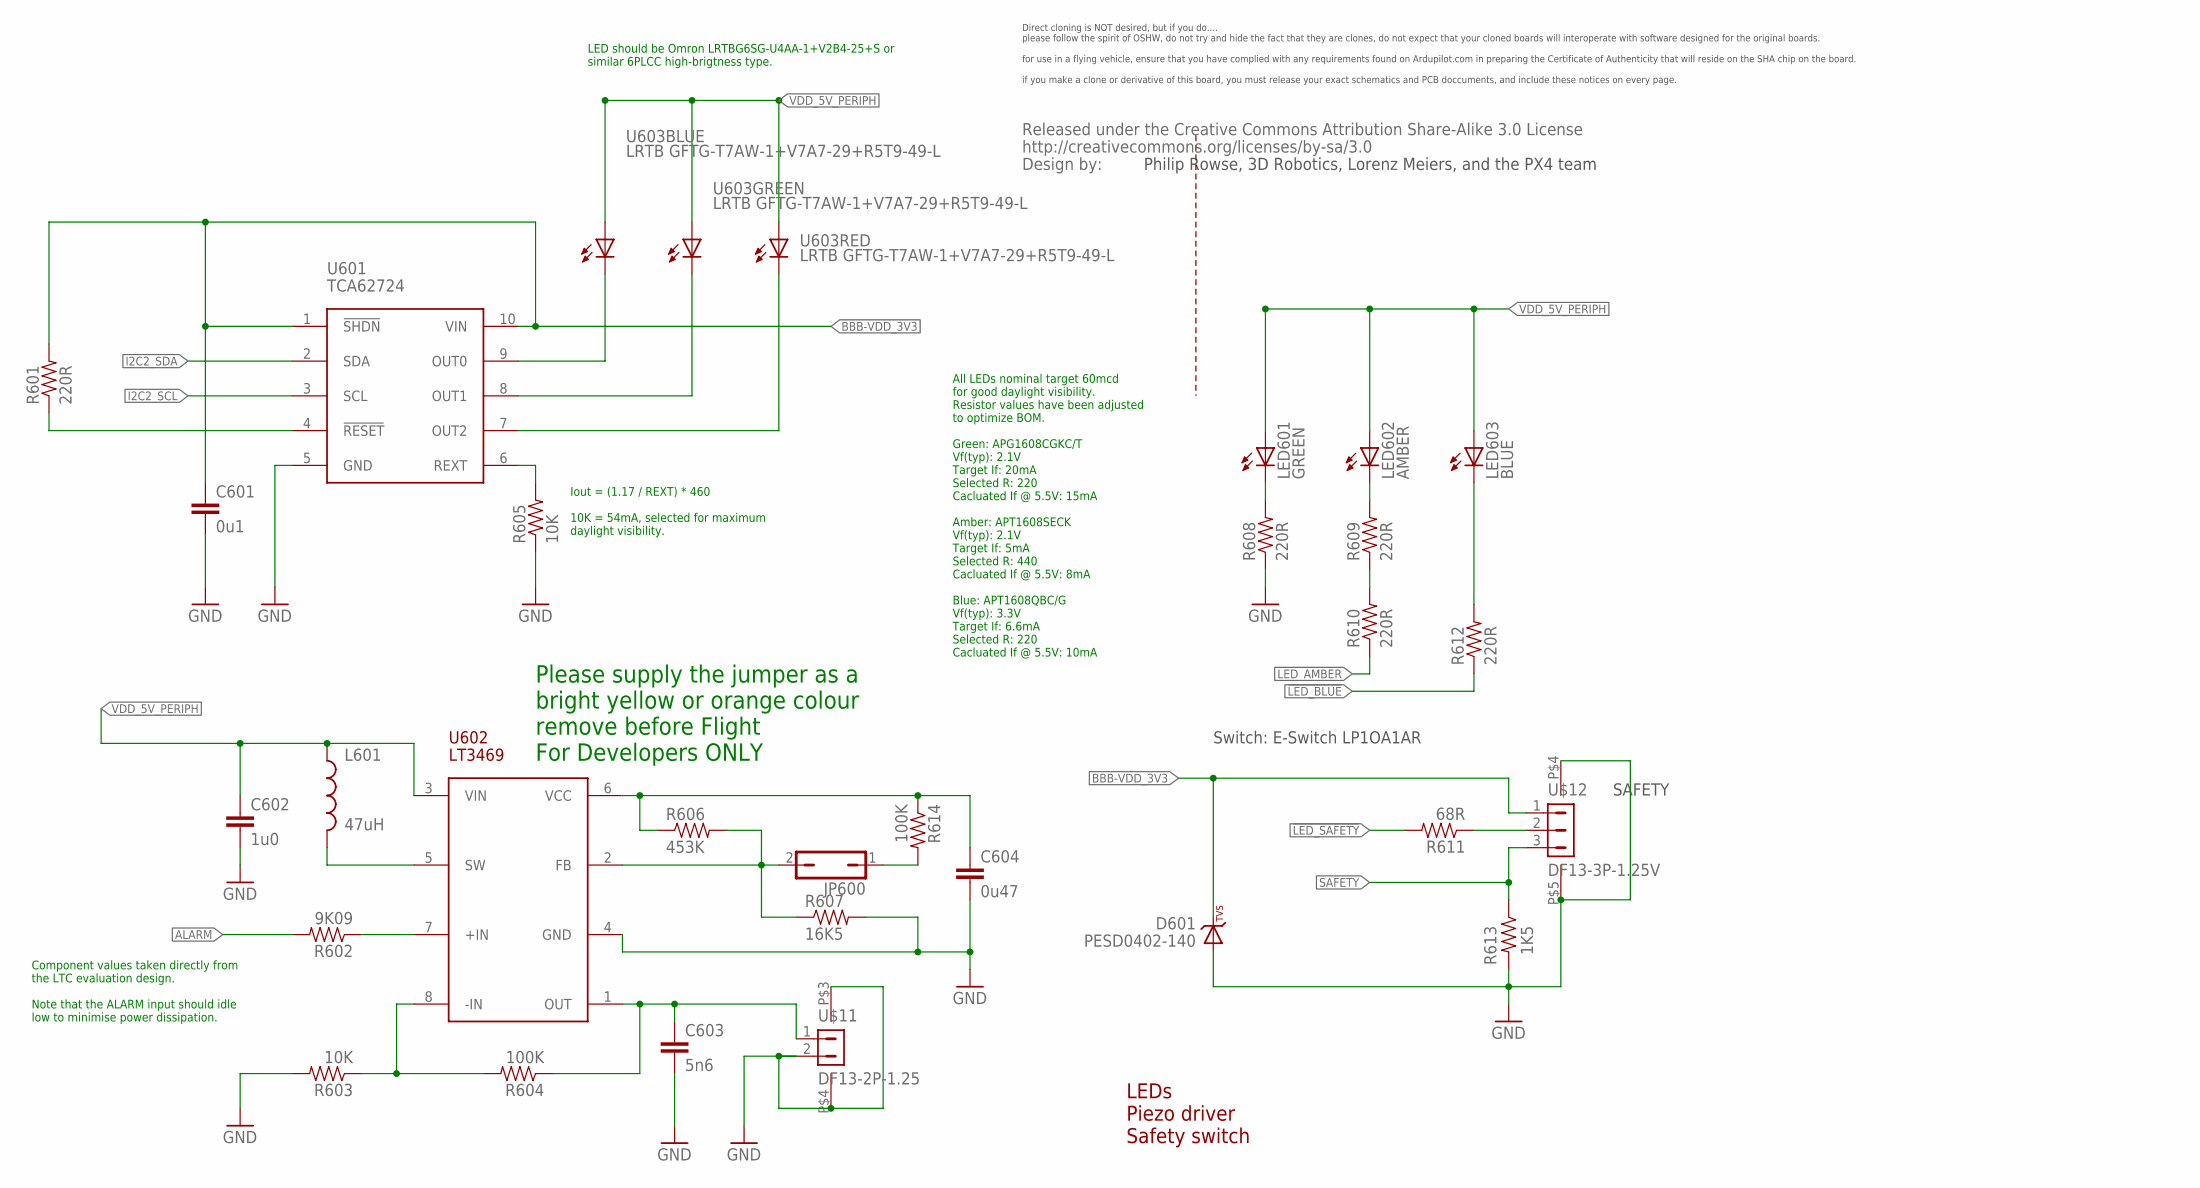
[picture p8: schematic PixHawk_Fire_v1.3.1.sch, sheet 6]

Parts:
C601: 0u1; 0402-CAP; PARTNO CC0402ZRY5V7BB104
C602: 1u0; 0603-CAP; PARTNO CC0603ZRY5V7BB105
C603: 5n6; 0402-CAP; PARTNO CC0402KRX7R7BB562
C604: 0u47; 0402-CAP; PARTNO C1005X5R1C474K050BC
D601: PESD0402-140; 0402-TVS; PARTNO PESD0402-140
JP600: JP1Q; JP1; PARTNO 1-87215-0
L601: 47uH; 0805-IND; PARTNO MLZ2012M470W
LED601: GREEN; 0603-LED; PARTNO APTD1608CGCK
LED602: AMBER; 0603-LED; PARTNO APTD1608SECK
LED603: BLUE; 0603-LED; PARTNO APTD1608QBC/D
R601, R608, R609, R610, R612: 220R; 0402-RES; PARTNO RC0402FR-07220RL
R602: 9K09; 0402-RES; PARTNO RMCF0402FT9K09
R603, R605: 10K; 0402-RES; PARTNO ERA-2AEB103X
R604, R614: 100K; 0402-RES; PARTNO RC0402FR-07100KL
R606: 453K; 0402-RES; PARTNO RMCF0402FT453K
R607: 16K5; 0402-RES; PARTNO RMCF0402FT16K5
R611: 68R; 0402-RES; PARTNO RC0402FR-0768RL
R613: 1K5; 0402-RES; PARTNO RC0402FR-071K5L
U601: TCA62724FMG; SON10; PARTNO TCA62724FMG
U602: LT3469; SOT23-8; PARTNO LT3469ETS8
U603: LRTB GFTG-T7AW-1+V7A7-29+R5T9-49-L; 6-PLCC; PARTNO LRTB GFTG-T7AW-1+V7A7-29+R5T9-49-L
U$10: CREATIVE_COMMONS
U$11: DF13-2P-1.25; DF13C-2P-1.25V; PARTNO DF13C-2P-1.25V(20)
U$12: DF13-3P-1.25V; DF13C-3P-1.25V; PARTNO DF13C-3P-1.25V(20)

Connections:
!LED_AMBER: R610.P$1 (1); also elsewhere on the board
!LED_BLUE: R612.P$1 (1); also elsewhere on the board
!LED_SAFETY: R611.P$2 (2); also elsewhere on the board
ALARM: R602.P$2 (2); also elsewhere on the board
BBB-VDD_3V3: C601.P$1 (1), D601.C, R601.P$2 (2), U601.1 (!SHDN), U601.10 (VIN), U$12.1; also elsewhere on the board
GND: C601.P$2 (2), C602.P$2 (2), C603.P$2 (2), C604.P$2 (2), D601.A, R603.P$2 (2), R605.P$1 (1), R607.P$2 (2), R608.P$1 (1), R613.P$2 (2), U601.5 (GND), U602.4 (GND), U$11.2, U$11.P$3, U$11.P$4, U$12.P$4, U$12.P$5; also elsewhere on the board
I2C2_SCL: U601.3 (SCL); also elsewhere on the board
I2C2_SDA: U601.2 (SDA); also elsewhere on the board
unnamed: R601.P$1 (1), U601.4 (!RESET)
unnamed: LED603.C, R612.P$2 (2)
unnamed: JP600.2, R606.P$2 (2), R607.P$1 (1), U602.2 (FB)
unnamed: R603.P$1 (1), R604.P$2 (2), U602.8 (-IN)
unnamed: C603.P$1 (1), R604.P$1 (1), U602.1 (OUT), U$11.1
unnamed: R602.P$1 (1), U602.7 (+IN)
unnamed: LED601.C, R608.P$2 (2)
unnamed: L601.P$2 (2), U602.5 (SW)
unnamed: C604.P$1 (1), R606.P$1 (1), R614.P$1 (1), U602.6 (VCC)
unnamed: R609.P$1 (1), R610.P$2 (2)
unnamed: LED602.C, R609.P$2 (2)
unnamed: JP600.1, R614.P$2 (2)
unnamed: R611.P$1 (1), U$12.2
unnamed: R605.P$2 (2), U601.6 (REXT)
RGB_LED_3: U601.9 (OUT0), U603.C1 (C)
RGB_LED_4: U601.8 (OUT1), U603.C2 (C)
RGB_LED_14: U601.7 (OUT2), U603.C3 (C)
SAFETY: R613.P$1 (1), U$12.3; also elsewhere on the board
VDD_5V_PERIPH: C602.P$1 (1), L601.P$1 (1), LED601.A, LED602.A, LED603.A, U602.3 (VIN), U603.A1 (A), U603.A2 (A), U603.A3 (A); also elsewhere on the board

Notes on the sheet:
LEDs Piezo driver Safety switch
Switch: E-Switch LP1OA1AR
SAFETY
LED should be Omron LRTBG6SG-U4AA-1+V2B4-25+S or similar 6PLCC high-brigtness type.
Iout = (1.17 / REXT) * 460 10K = 54mA, selected for maximum daylight visibility.
All LEDs nominal target 60mcd for good daylight visibility. Resistor values have been adjusted to optimize BOM. Green: APG1608CGKC/T Vf(typ): 2.1V Target If: 20mA Selected R: 220 Cacluated If @ 5.5V: 15mA Amber: APT1608SECK Vf(typ): 2.1V Target If: 5mA Selected R: 440 Cacluated If @ 5.5V: 8mA Blue: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
Component values taken directly from the LTC evaluation design. Note that the ALARM input should idle low to minimise power dissipation.
Please supply the jumper as a bright yellow or orange colour remove before Flight For Developers ONLY
Philip Rowse, 3D Robotics, Lorenz Meiers, and the PX4 team
Direct cloning is NOT desired, but if you do.... please follow the spirit of OSHW, do not try and hide the fact that they are clones, do not expect that your cloned boards will interoperate with software designed for the original boards. for use in a flying vehicle, ensure that you have complied wi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

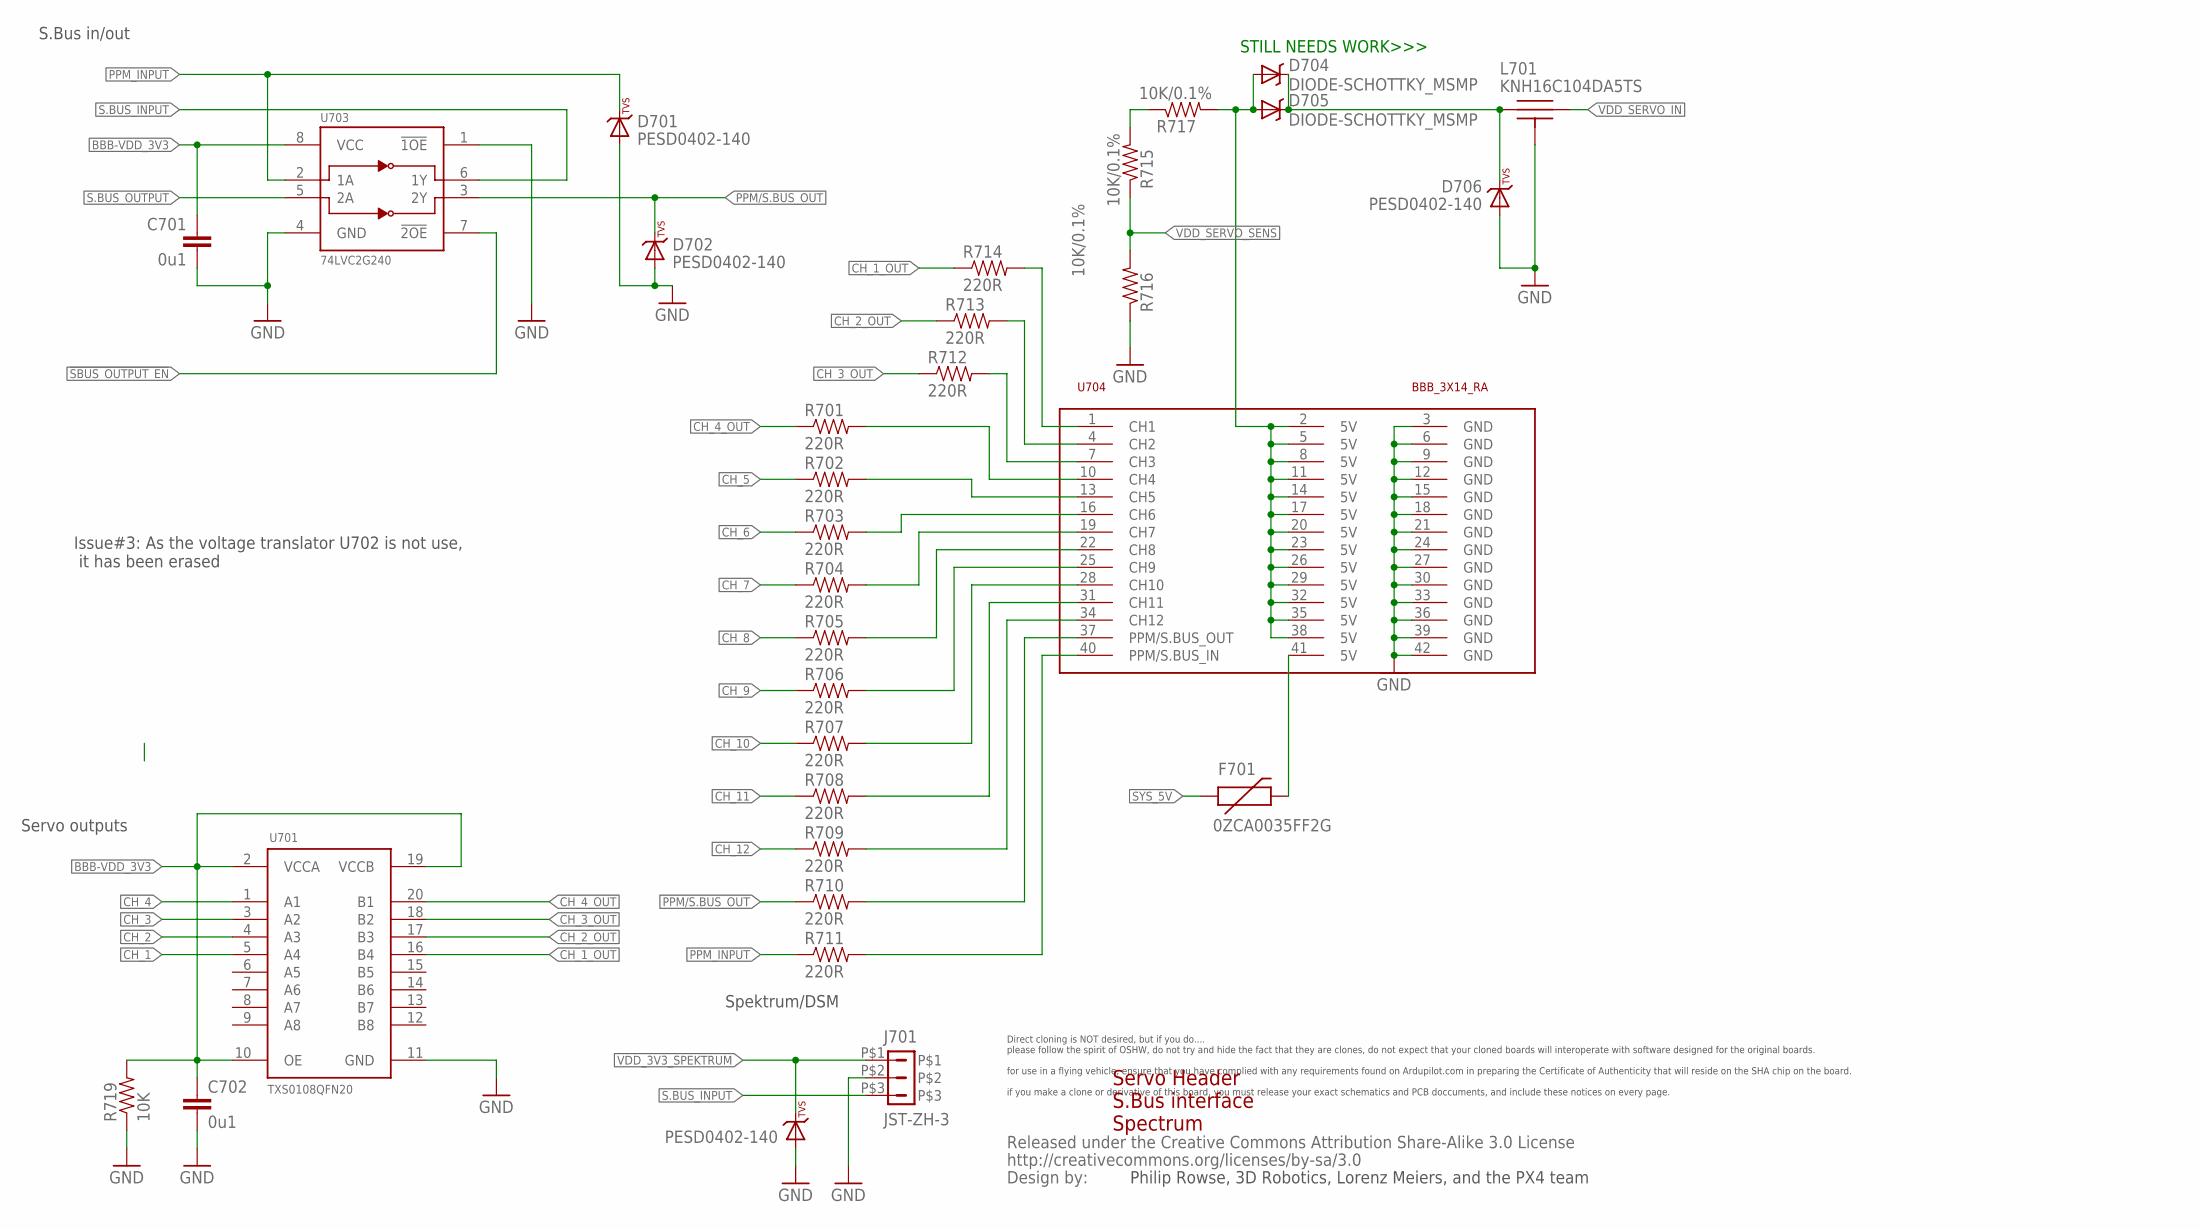
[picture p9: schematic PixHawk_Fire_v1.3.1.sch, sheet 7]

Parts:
C701, C702: 0u1; 0402-CAP; PARTNO CC0402ZRY5V7BB104
D701, D702, D703, D706: PESD0402-140; 0402-TVS; PARTNO PESD0402-140
D704, D705: DIODE-SCHOTTKY_MSMP; MICROSMP; PARTNO SS14
F701: 0ZCA0035FF2G; PTC-1206; PARTNO 0ZCA0035FF2G
J701: JST-ZH-3; JST-ZH-SMT-VERTICAL; PARTNO B3B-ZR-SM4-TF (LF)(SN)(P)
L701: KNH16C104DA5TS; KYOCERA-KNH16-DA; PARTNO KNH16C104DA5TS
R701, R702, R703, R704, R705, R706, R707, R708, R709, R710, R711, R712, R713, R714: 220R; 0402-RES; PARTNO RC0402FR-07220RL
R715, R716, R717: 10K/0.1%; 0402-RES; PARTNO ERA-2AEB103X
R719: 10K; 0402-RES; PARTNO ERA-2AEB103X
U701: TXS0108QFN20; QFN20-RGY; PARTNO TXS0108ERGYR
U703: 74LVC2G240; TSSOP8_SOT505-2; PARTNO 74LVC2G240DP,125
U704: BBB_3X14_RA; 3X14RA; PARTNO 07579
U$13: CREATIVE_COMMONS

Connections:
!SBUS_OUTPUT_EN: U703.7 (!2OE); also elsewhere on the board
BBB-VDD_3V3: C701.P$1 (1), C702.P$1 (1), R719.P$2 (2), U701.2 (VCCA), U701.10 (OE), U701.19 (VCCB), U703.8 (VCC); also elsewhere on the board
CH_1: U701.5 (A4); also elsewhere on the board
CH_1_OUT: R714.P$1 (1), U701.16 (B4)
CH_2: U701.4 (A3); also elsewhere on the board
CH_2_OUT: R713.P$1 (1), U701.17 (B3)
CH_3: U701.3 (A2); also elsewhere on the board
CH_3_OUT: R712.P$1 (1), U701.18 (B2)
CH_4: U701.1 (A1); also elsewhere on the board
CH_4_OUT: R701.P$1 (1), U701.20 (B1)
CH_5: R702.P$1 (1); also elsewhere on the board
CH_6: R703.P$1 (1); also elsewhere on the board
CH_7: R704.P$1 (1); also elsewhere on the board
CH_8: R705.P$1 (1); also elsewhere on the board
CH_9: R706.P$1 (1); also elsewhere on the board
CH_10: R707.P$1 (1); also elsewhere on the board
CH_11: R708.P$1 (1); also elsewhere on the board
CH_12: R709.P$1 (1); also elsewhere on the board
FMU-CH6-PROT: R708.P$2 (2), U704.31 (CH11)
GND: C701.P$2 (2), C702.P$2 (2), D701.A, D702.A, D703.A, D706.A, J701.P$2, L701.P$3, L701.P$4, L701.P$5, R716.P$1 (1), R719.P$1 (1), U701.11 (GND), U703.1 (!1OE), U703.4 (GND), U704.3 (GND), U704.6 (GND), U704.9 (GND), U704.12 (GND), U704.15 (GND), U704.18 (GND), U704.21 (GND), U704.24 (GND), U704.27 (GND), U704.30 (GND), U704.33 (GND), U704.36 (GND), U704.39 (GND), U704.42 (GND); also elsewhere on the board
IO-CH1-PROT: R707.P$2 (2), U704.28 (CH10)
IO-CH8-PROT: R712.P$2 (2), U704.7 (CH3)
unnamed: R715.P$2 (2), R717.P$1 (1)
unnamed: D704.CATHODE (C), D705.CATHODE (C), D706.C, L701.P$1
unnamed: D704.ANODE (A), D705.ANODE (A), R717.P$2 (2), U704.2 (5V), U704.5 (5V), U704.8 (5V), U704.11 (5V), U704.14 (5V), U704.17 (5V), U704.20 (5V), U704.23 (5V), U704.26 (5V), U704.29 (5V), U704.32 (5V), U704.35 (5V), U704.38 (5V)
unnamed: F701.2, U704.41 (5V)
unnamed: R701.P$2 (2), U704.10 (CH4)
unnamed: R709.P$2 (2), U704.34 (CH12)
unnamed: R702.P$2 (2), U704.13 (CH5)
unnamed: R703.P$2 (2), U704.16 (CH6)
unnamed: R704.P$2 (2), U704.19 (CH7)
unnamed: R705.P$2 (2), U704.22 (CH8)
unnamed: R706.P$2 (2), U704.25 (CH9)
unnamed: R710.P$2 (2), U704.37 (PPM/S.BUS_OUT)
unnamed: R711.P$2 (2), U704.40 (PPM/S.BUS_IN)
unnamed: R713.P$2 (2), U704.4 (CH2)
PPM-SBUS-PROT: R714.P$2 (2), U704.1 (CH1)
PPM/S.BUS_OUT: D702.C, R710.P$1 (1), U703.3 (2Y)
PPM_INPUT: D701.C, R711.P$1 (1), U703.2 (1A); also elsewhere on the board
S.BUS_INPUT: J701.P$3, U703.6 (1Y); also elsewhere on the board
S.BUS_OUTPUT: U703.5 (2A); also elsewhere on the board
SYS_5V: F701.1; also elsewhere on the board
VDD_3V3_SPEKTRUM: D703.C, J701.P$1; also elsewhere on the board
VDD_SERVO_IN: L701.P$2; also elsewhere on the board
VDD_SERVO_SENS: R715.P$1 (1), R716.P$2 (2); also elsewhere on the board

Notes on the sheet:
Servo Header S.Bus interface Spectrum
S.Bus in/out
Servo outputs
Spektrum/DSM
STILL NEEDS WORK>>>
Philip Rowse, 3D Robotics, Lorenz Meiers, and the PX4 team
Direct cloning is NOT desired, but if you do.... please follow the spirit of OSHW, do not try and hide the fact that they are clones, do not expect that your cloned boards will interoperate with software designed for the original boards. for use in a flying vehicle, ensure that you have complied wi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
Issue#3: As the voltage translator U702 is not use, it has been erased

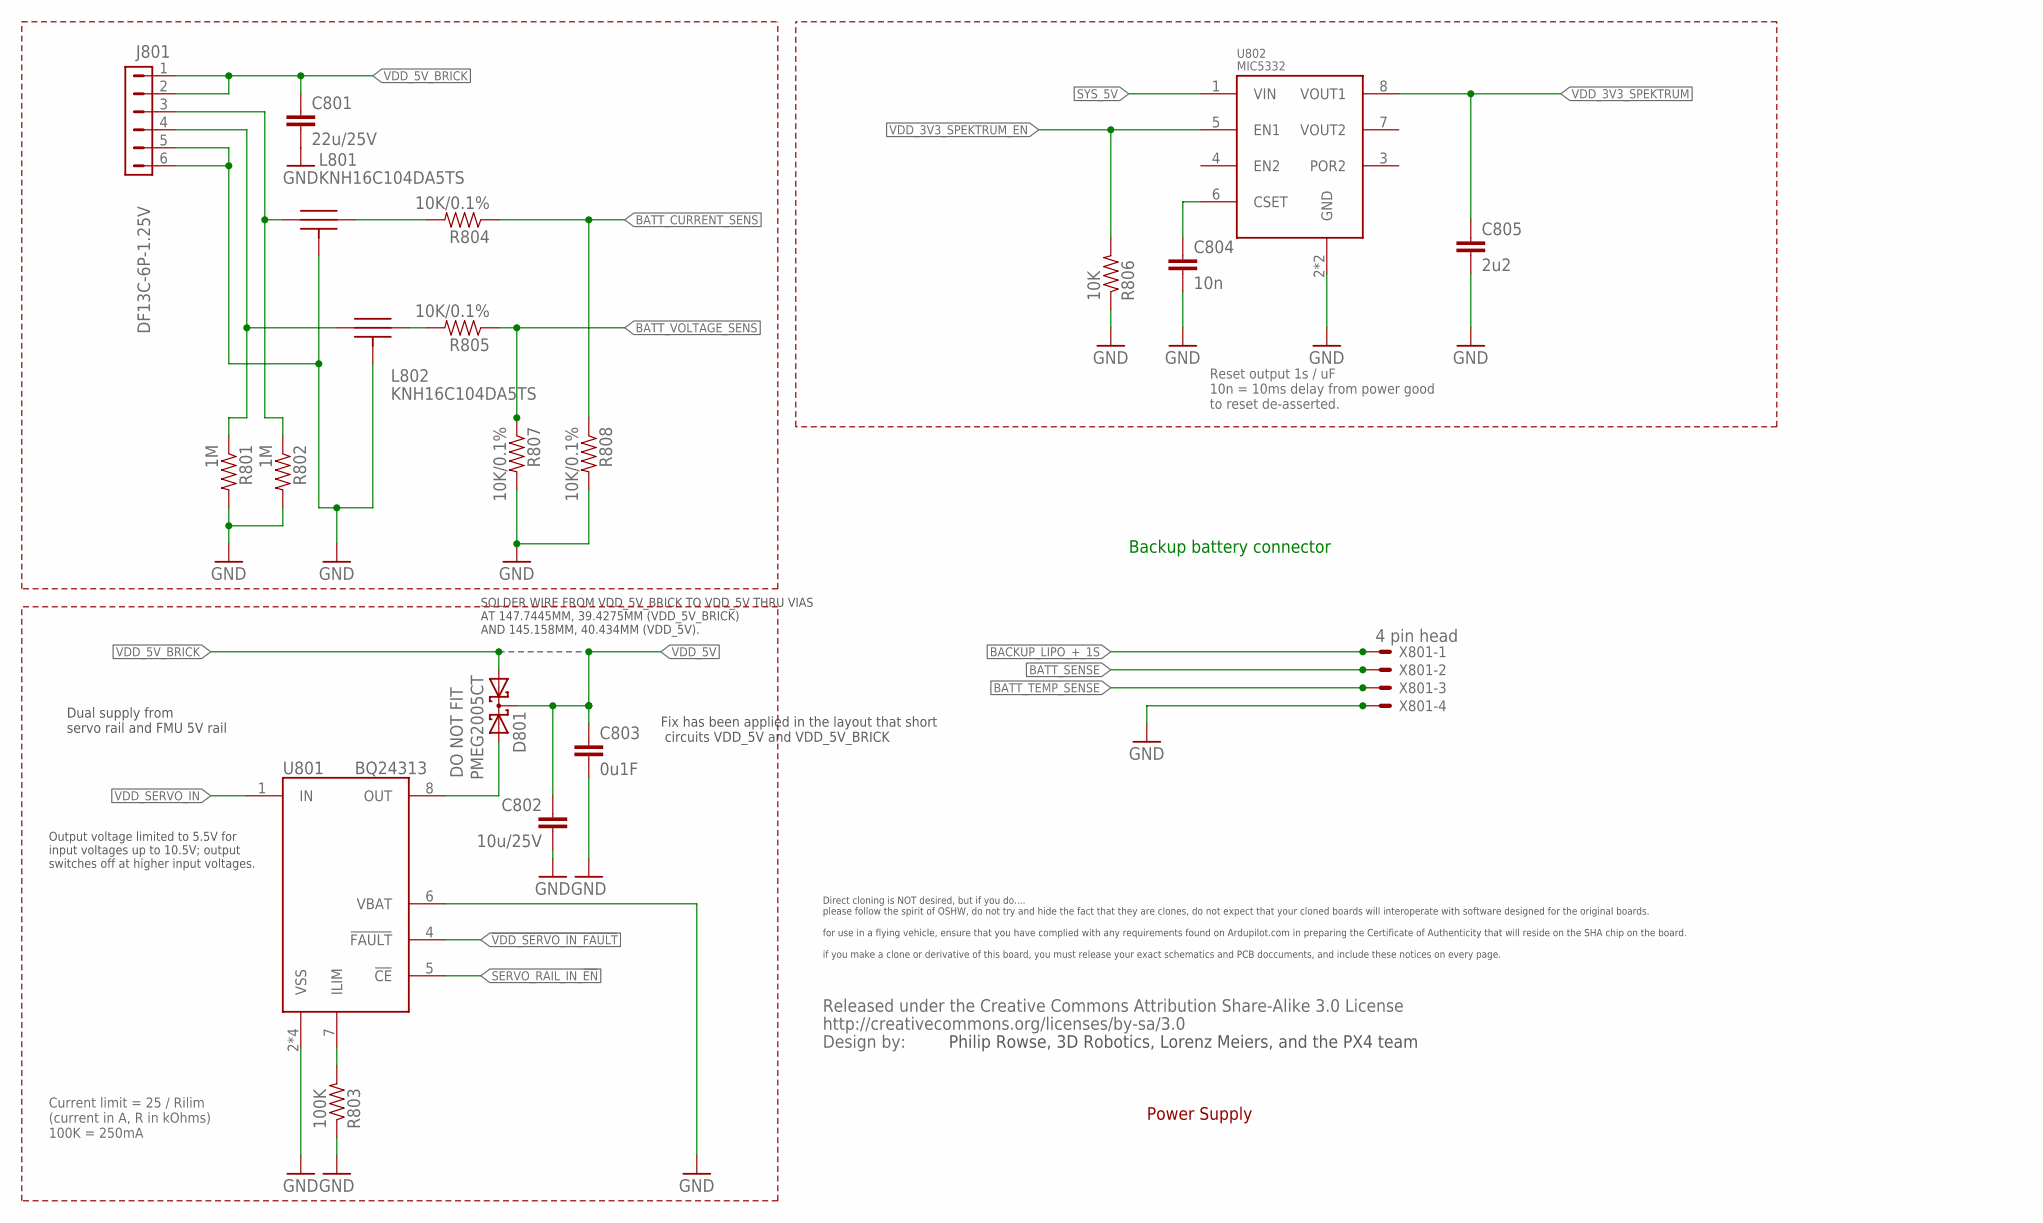
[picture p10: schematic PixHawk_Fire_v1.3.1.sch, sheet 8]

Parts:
C801: 22u/25V; 0805-CAP; PARTNO CL21A226MAQNNNE
C802: 10u/25V; 0805-CAP; PARTNO CL21A106KAYNNNE
C803: 0u1F; 0402-CAP; PARTNO CC0402ZRY5V7BB104
C804: 10n; 0402-CAP; PARTNO CC0402KRX7R7BB103
C805: 2u2; 0402-CAP; PARTNO CC0603ZRY5V6BB225
D801: PMEG2005CT; SOT23-3; PARTNO DO NOT FIT
J801: DF13C-6P-1.25V; PARTNO DF13C-6P-1.25V(20)
L801, L802: KNH16C104DA5TS; KYOCERA-KNH16-DA; PARTNO KNH16C104DA5TS
R801, R802: 1M; 0402-RES; PARTNO RC0402FR-071ML
R803: 100K; 0402-RES; PARTNO RC0402FR-07100KL
R804, R805, R807, R808: 10K/0.1%; 0402-RES; PARTNO ERA-2AEB103X
R806: 10K; 0402-RES; PARTNO ERA-2AEB103X
U801: BQ24313; QFN8-DSG; PARTNO BQ24313DSGT
U802: MIC5332; MLF-8-EPAD; PARTNO MIC5332-SSYMT
U$14: CREATIVE_COMMONS
X801: 4 pin head; 53047-04; PARTNO 53047-04

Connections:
!VDD_SERVO_IN_FAULT: U801.4 (!FAULT); also elsewhere on the board
BACKUP_LIPO_+_1S: X801.1; also elsewhere on the board
BATT_CURRENT_SENS: R804.P$1 (1), R808.P$1 (1); also elsewhere on the board
BATT_CURRENT_SENS_PROT: J801.3, L801.P$1, R802.P$1 (1)
BATT_SENSE: X801.2; also elsewhere on the board
BATT_TEMP_SENSE: X801.3; also elsewhere on the board
BATT_VOLTAGE_SENS: R805.P$1 (1), R807.P$1 (1); also elsewhere on the board
BATT_VOLTAGE_SENS_PROT: J801.4, L802.P$1, R801.P$1 (1)
GND: C801.P$2 (2), C802.P$2 (2), C803.P$2 (2), C804.P$2 (2), C805.P$2 (2), J801.5, J801.6, L801.P$3, L801.P$4, L801.P$5, L802.P$3, L802.P$4, L802.P$5, R801.P$2 (2), R802.P$2 (2), R803.P$1 (1), R806.P$1 (1), R807.P$2 (2), R808.P$2 (2), U801.2 (VSS), U801.6 (VBAT), U801.GND (VSS), U801.P$2 (VSS), U801.P$3 (VSS), U802.2 (GND), U802.GND, X801.4; also elsewhere on the board
unnamed: D801.2 (A2), U801.8 (OUT)
unnamed: R803.P$2 (2), U801.7 (ILIM)
unnamed: L802.P$2, R805.P$2 (2)
unnamed: L801.P$2, R804.P$2 (2)
unnamed: C804.P$1 (1), U802.6 (CSET)
SERVO_RAIL_IN_!EN: U801.5 (!CE); also elsewhere on the board
SYS_5V: U802.1 (VIN); also elsewhere on the board
VDD_3V3_SPEKTRUM: C805.P$1 (1), U802.8 (VOUT1); also elsewhere on the board
VDD_3V3_SPEKTRUM_EN: R806.P$2 (2), U802.5 (EN1); also elsewhere on the board
VDD_5V: C802.P$1 (1), C803.P$1 (1), D801.3 (CC); also elsewhere on the board
VDD_5V_BRICK: C801.P$1 (1), D801.1 (A1), J801.1, J801.2; also elsewhere on the board
VDD_SERVO_IN: U801.1 (IN); also elsewhere on the board

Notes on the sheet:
Dual supply from servo rail and FMU 5V rail
Current limit = 25 / Rilim (current in A, R in kOhms) 100K = 250mA
Power Supply
Reset output 1s / uF 10n = 10ms delay from power good to reset de-asserted.
Output voltage limited to 5.5V for input voltages up to 10.5V; output switches off at higher input voltages.
Backup battery connector
SOLDER WIRE FROM VDD_5V_BRICK TO VDD_5V THRU VIAS AT 147.7445MM, 39.4275MM (VDD_5V_BRICK) AND 145.158MM, 40.434MM (VDD_5V).
Philip Rowse, 3D Robotics, Lorenz Meiers, and the PX4 team
Direct cloning is NOT desired, but if you do.... please follow the spirit of OSHW, do not try and hide the fact that they are clones, do not expect that your cloned boards will interoperate with software designed for the original boards. for use in a flying vehicle, ensure that you have complied wi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
Fix has been applied in the layout that short circuits VDD_5V and VDD_5V_BRICK

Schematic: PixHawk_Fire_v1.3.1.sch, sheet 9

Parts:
ADC_PR: PAD.04; PAD.04X.04; PARTNO *
CAN_H: PAD.04; PAD.04X.04; PARTNO *
CAN_L: PAD.04; PAD.04X.04; PARTNO *
GND, GND.: PAD.04; PAD.04X.04; PARTNO *
JP901, JP902: FIDUCIAL1.5X3; FIDUCIAL-1.5X3; PARTNO *
M3_MOUNT901, M3_MOUNT902, M3_MOUNT903, M3_MOUNT904: MOUNT-HOLE3.1MM; MOUNT-HOLE3.1; PARTNO *
OSHW_LOGO: OSHW-LOGOS; OSHW-LOGO-S; PARTNO *
S1RX, S1TX, S2RX, S2TX, S3RX, S3TX, S4RX, S4TX: PAD.04; PAD.04X.04; PARTNO *
U$15: CREATIVE_COMMONS
VDDA_3V901: PAD.04; PAD.04X.04; PARTNO *
VDD_3V901, VDD_5V_BRICK, VDD_5V_IN: PAD.04; PAD.04X.04; PARTNO *

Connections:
BBB-VDD_3V3: VDD_3V901.P$1; also elsewhere on the board
CAN_H: CAN_H.P$1; also elsewhere on the board
CAN_L: CAN_L.P$1; also elsewhere on the board
GND: GND.P$1, GND..P$1; also elsewhere on the board
PRESSURE_SENS_IN: ADC_PR.P$1; also elsewhere on the board
S.BUS_INPUT: S3RX.P$1; also elsewhere on the board
S.BUS_OUTPUT: S3TX.P$1; also elsewhere on the board
SERIAL1_RX: S1RX.P$1; also elsewhere on the board
SERIAL1_TX: S1TX.P$1; also elsewhere on the board
SERIAL2_RX: S2RX.P$1; also elsewhere on the board
SERIAL2_TX: S2TX.P$1; also elsewhere on the board
SERIAL4_RX: S4RX.P$1; also elsewhere on the board
SERIAL4_TX: S4TX.P$1; also elsewhere on the board
SYS_5V: VDD_5V_IN.P$1; also elsewhere on the board
VDD_3V3_SENSORS: VDDA_3V901.P$1; also elsewhere on the board
VDD_5V_BRICK: VDD_5V_BRICK.P$1; also elsewhere on the board

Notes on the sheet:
Mounting holes to suit M3 fastener
and Richco R908 series spacer.
Use R908-5 spacers to stack with
other PX4 series boards (7.95 mm).
Production Testing Pads
Test and Fiducials
Minimum drill: 0.3 mm
Minimum trace width (use mm for traces): 0.15 mm
Minimum copper distance (all signals): 0.15 mm
Dimension / hole minimum distance: 0.2 mm
Layout grid: 4 mil, part grid: 4 mil. Dimensions / hole positions: 0.5 mm
Board: FR4 black, 1.0 mm. Solder stop on vias < 0.6 mm.
Signoff rules: Footprint checked, pinmap checked, schematic checked, cross-references to other pages checked.
Routing: 1: general/escape 2: ground 3: horizontal 4: vertical 5: power 6: general/escape
Fiducials for machine vision alignment.
Parts: Resistors: 0402 / 1% unless specified otherwise Capacitors: 0402 to 1206, ceramic, voltage rating: 10V unless specified
Philip Rowse, 3D Robotics, Lorenz Meiers, and the PX4 team
Direct cloning is NOT desired, but if you do.... please follow the spirit of OSHW, do not try and hide the fact that they are clones, do not expect that your cloned boards will interoperate with software designed for the original boards. for use in a flying vehicle, ensure that you have complied wi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

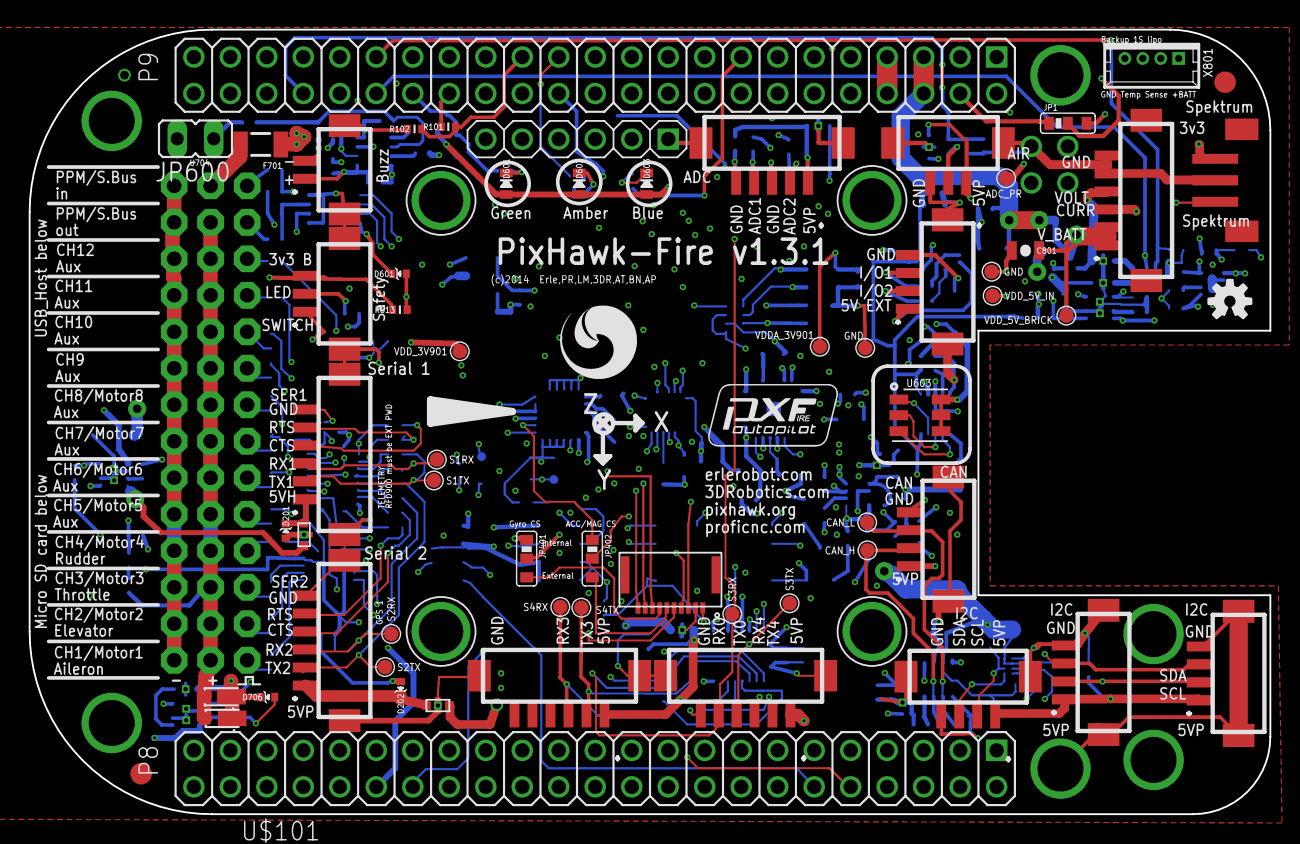
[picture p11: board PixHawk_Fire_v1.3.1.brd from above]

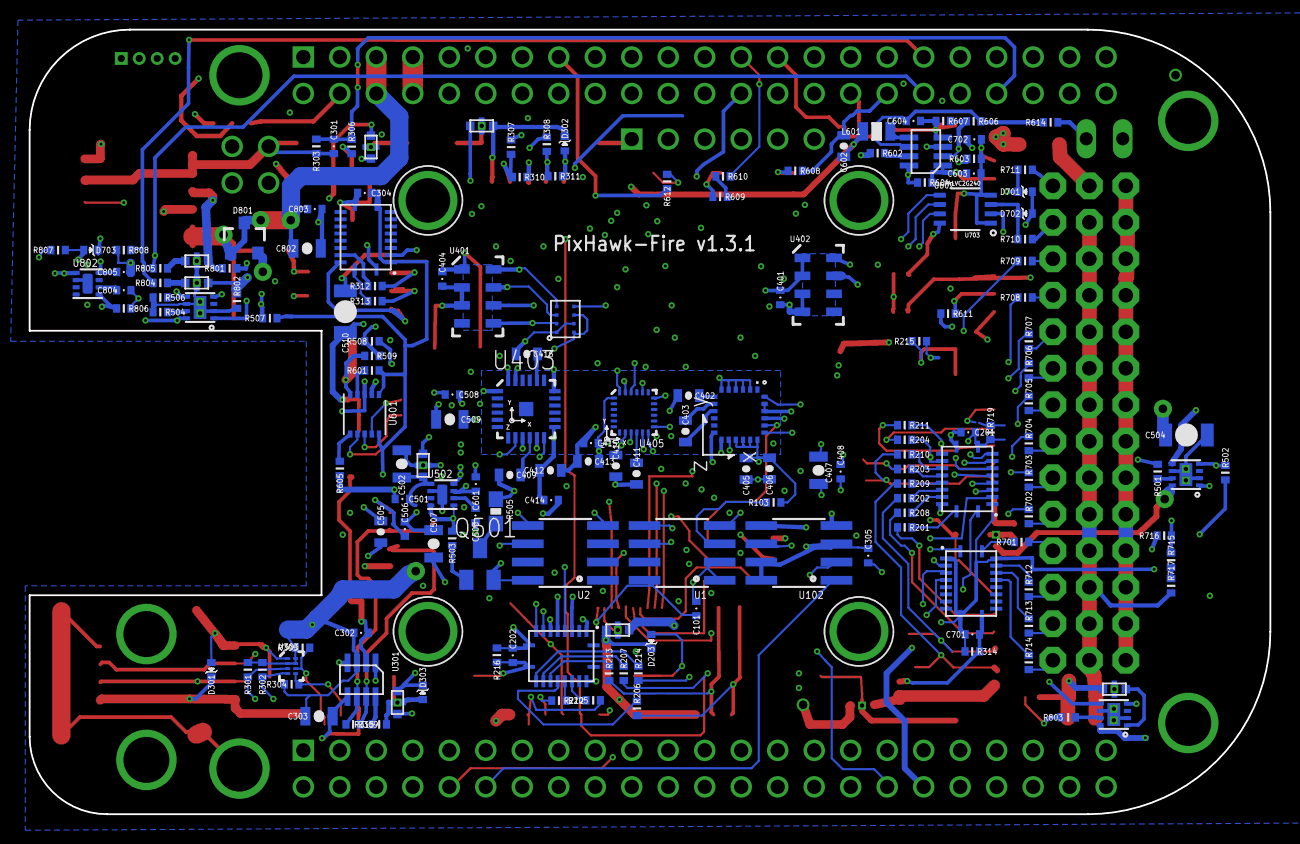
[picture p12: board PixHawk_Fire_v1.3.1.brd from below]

Board: 6 copper layers, 86.4 x 54.6 mm, 239 parts (165 on the bottom side), 191 nets.

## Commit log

2014-08-11 v1.1 with errors
    [PXF-amarillo.skp, PixHawk_Fire_v1.1.brd, PixHawk_Fire_v1.1.sch]
2014-08-13 Creation of v1.2, LSM9DSO issue fixed
    Sch and brd v1.2 creation and LSM9DSO issue reparation according to
    feedback
    [PixHawk_Fire_v1.2.brd, PixHawk_Fire_v1.2.sch]
2014-08-26 Fix in the layout names
    [PixHawk_Fire_v1.2.brd]
2014-09-01 Fixes in some typos with components
    [PixHawk_Fire_v1.2.brd]
2014-09-11 ISSUE#3 Fix
    Bypassing of the voltage translator. Modified pins: P8:
    33,35,39,40,41,42,43,44,45,46. Which are the signlas : USART4 RTS abd
    CTS nad CH6 to CH12
    [PixHawk_Fire_v1.3.brd, PixHawk_Fire_v1.3.sch]
2014-09-17 ISSUE#3 v2: Removal of the Voltage Trns. U702
    Removal of U702, R718 and C703. Retracing of this area. Notice there is
    a airwire in point 3880,929.5. I have tried to remove it with little
    success.
    [PixHawk_Fire_v1.3.brd, PixHawk_Fire_v1.3.sch]
2014-09-23 Address issue #2.
    This fix avoid having to hand solder a cable
    between VDD_5V and VDD_5V_BRICK. The fix
    allows to use the Power Module to power the
    board directly.
    [PixHawk_Fire_v1.3.sch]
2014-09-23 Minor fixes in the silscreen
    [PixHawk_Fire_v1.3.brd]
2014-10-02 Version 1.4, LSM9D -> MPU9255 change
    [PixHawk_Fire_v1.4.brd, PixHawk_Fire_v1.4.sch]
2014-10-02 Capacitor value and partno fix
    [PixHawk_Fire_v1.4.brd]
2014-10-03 MPU9255 testpad addition
    MPU9255 testpad addition, so is possible to solder a wire to make the
    next connection: MPU pin 1 ->3v3
    U404 /CS conexion fix
2014-10-07 PXF v1.3.1: Issue #11 fix
    Fix of the Issue #11:
    - LSM9D: pin -> NC and Pin 15, 16,17- > pin 18 connection
    - MPU9250 : Pin 1 -> 3v3
    [PixHawk_Fire_v1.3.1.brd, PixHawk_Fire_v1.3.1.sch]
2014-10-08 Modify README, minor changes in the board layout
    [PixHawk_Fire_v1.3.1.brd, PixHawk_Fire_v1.3.1.sch]

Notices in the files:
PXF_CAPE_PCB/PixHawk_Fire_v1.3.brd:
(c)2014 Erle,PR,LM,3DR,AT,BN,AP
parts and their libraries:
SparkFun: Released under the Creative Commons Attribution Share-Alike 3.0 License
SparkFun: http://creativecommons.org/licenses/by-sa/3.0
